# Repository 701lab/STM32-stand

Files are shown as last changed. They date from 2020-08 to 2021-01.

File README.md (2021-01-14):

# STM32 stand

В этом репозитории хранятся все исходные файлы печатных плат для лабораторного стенда по программированию STM32, разработанного в БГУИР.

Печатные платы разрабатывались с использованием Autodesk Eagle 9.6.1.

Кроме исходных файлов в данном репозитории можно также найти:
* файлы для заказа печатных плат;
* файлы для сборки печатных плат;
* документацию на платы оформленную почти под ЕСКД.

Данные файлы распространяются свободно и могут быть свободно использованы.

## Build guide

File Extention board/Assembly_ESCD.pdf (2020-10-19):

Формат А4

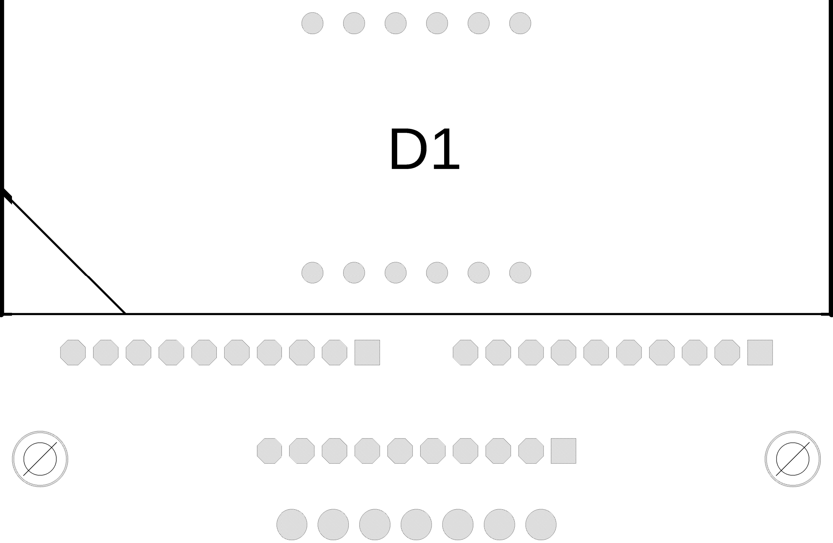
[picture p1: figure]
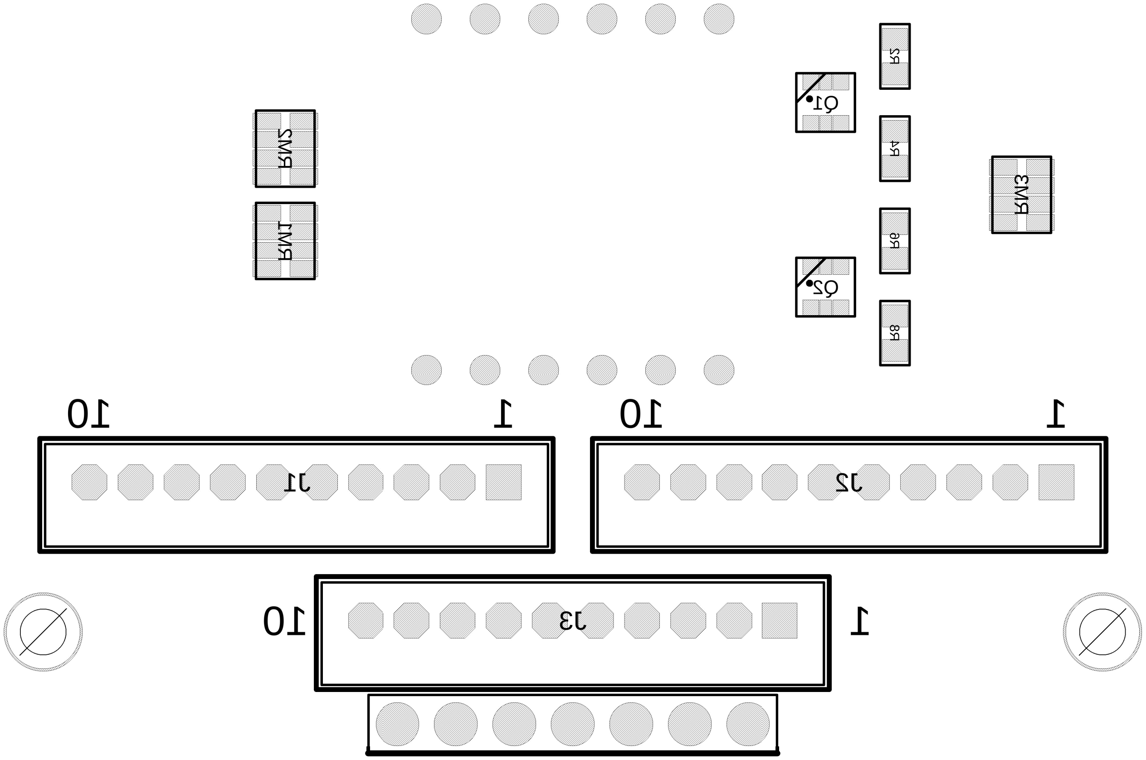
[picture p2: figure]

Изм. | Лист | № докум. | Подп. | Дата
Разраб.
Пров.
Лит | Лист | Листов

# ГУИР.411711.001 ПЭ3

Плата модуля расширения

Схема расположения

## БГУИР, каф. СУ

1 | 1

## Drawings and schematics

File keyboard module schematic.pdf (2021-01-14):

Цифровые входы-выходы | 7-мисегментный индикатор | Подключение клавиатуры

# 10 J1

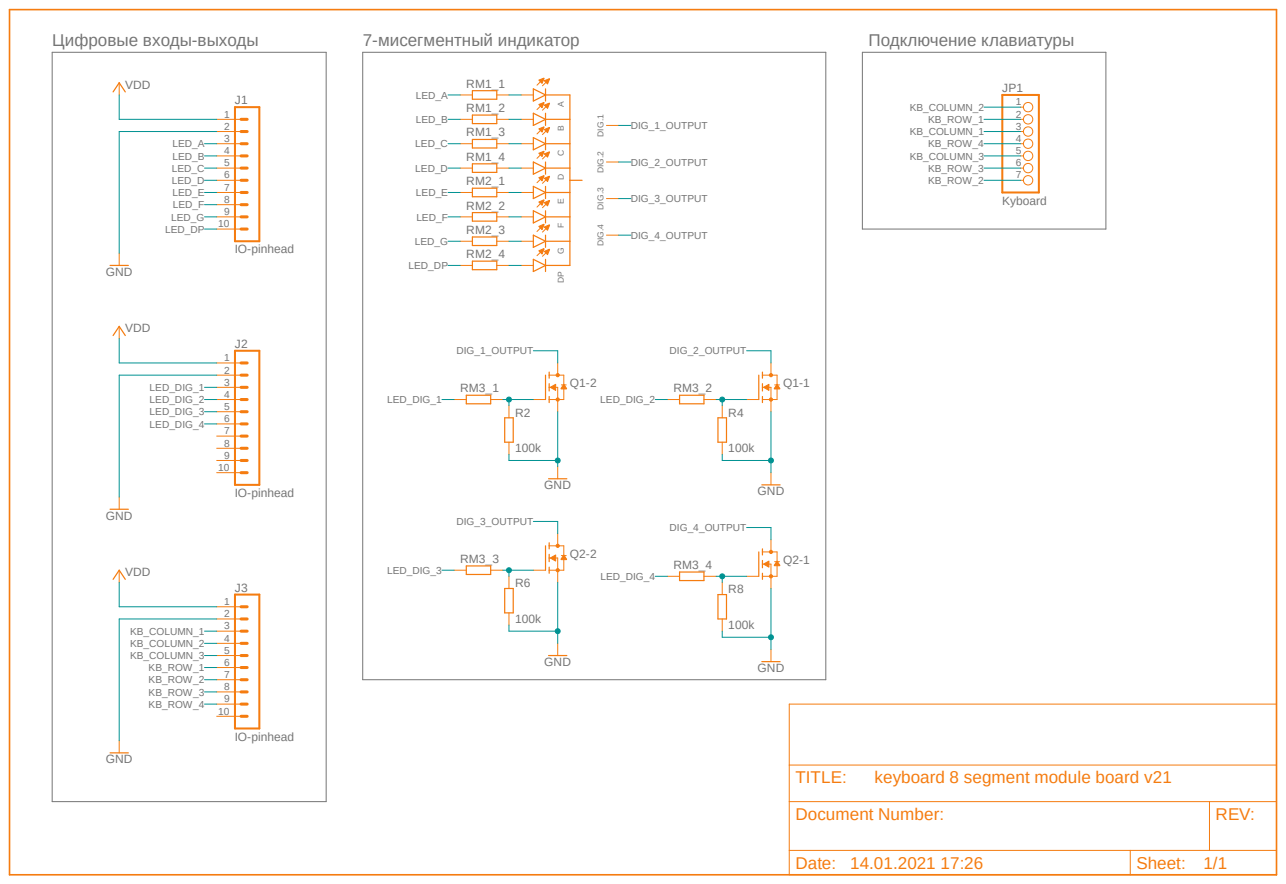
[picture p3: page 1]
VDD; GND; Kyboard; IO-pinhead; LED_A; LED_B; LED_C; LED_D; LED_E; LED_F; LED_G; LED_DIG_1; LED_DIG_2; LED_DIG_2 LED_DIG_1; LED_DIG_3; LED_DIG_4; KB_ROW_1; KB_COLUMN_1; KB_ROW_4; KB_COLUMN_3; KB_ROW_3; KB_ROW_2; KB_COLUMN_2; LED_DP; DIG_1_OUTPUT; DIG_2_OUTPUT; DIG_3_OUTPUT; DIG_4_OUTPUT; TITLE:

A B C D E F G DP DIG.1 DIG.2 DIG.3 DIG.4

keyboard 8 segment module board v21

Document Number: | REV:

Date: 14.01.2021 17:26 | Sheet: 1/1

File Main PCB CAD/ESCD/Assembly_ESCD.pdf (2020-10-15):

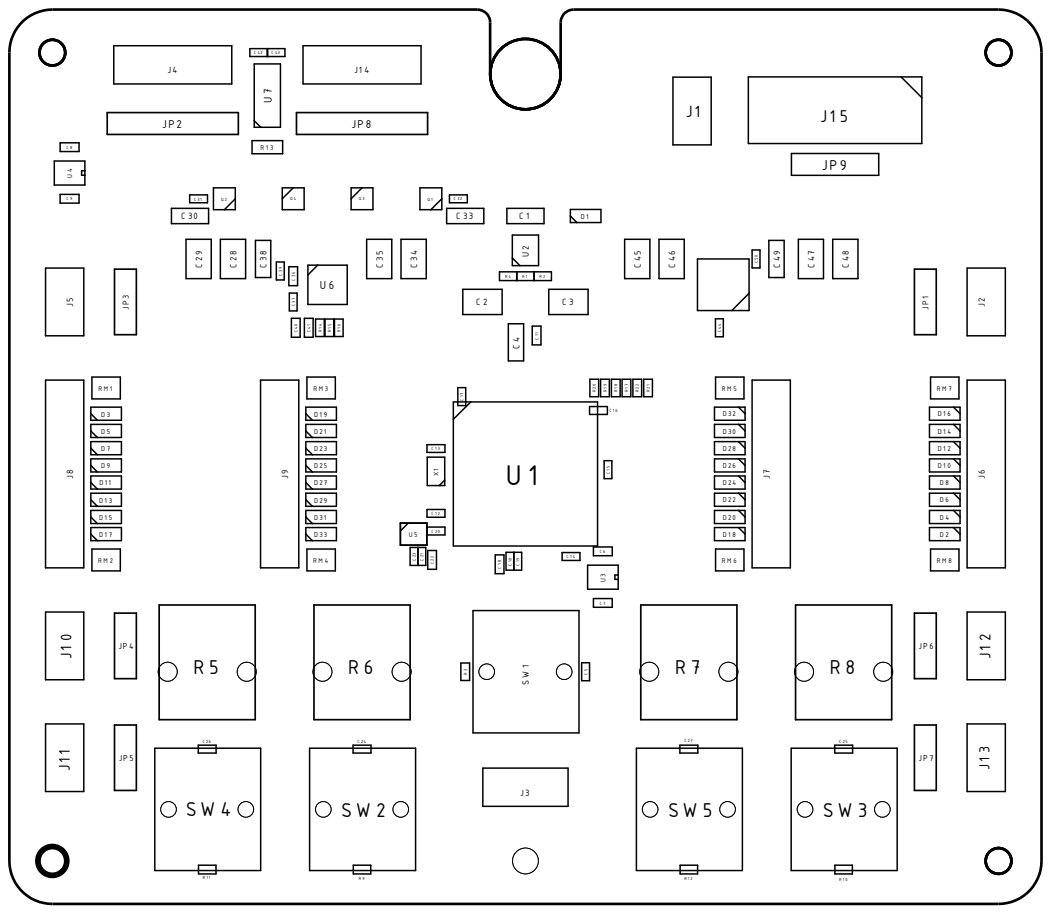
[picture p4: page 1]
Формат А4; Изм.; Лист; № докум.; Подп.; Дата; Разраб. Пров.; Лит; Листов; ГУИР.411711.001 ПЭ3; Плата управления стендом STM32; Схема расположения

БГУИР, каф. СУ

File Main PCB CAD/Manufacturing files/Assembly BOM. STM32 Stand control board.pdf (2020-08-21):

BOM. STM32 Stand control board | Electrical

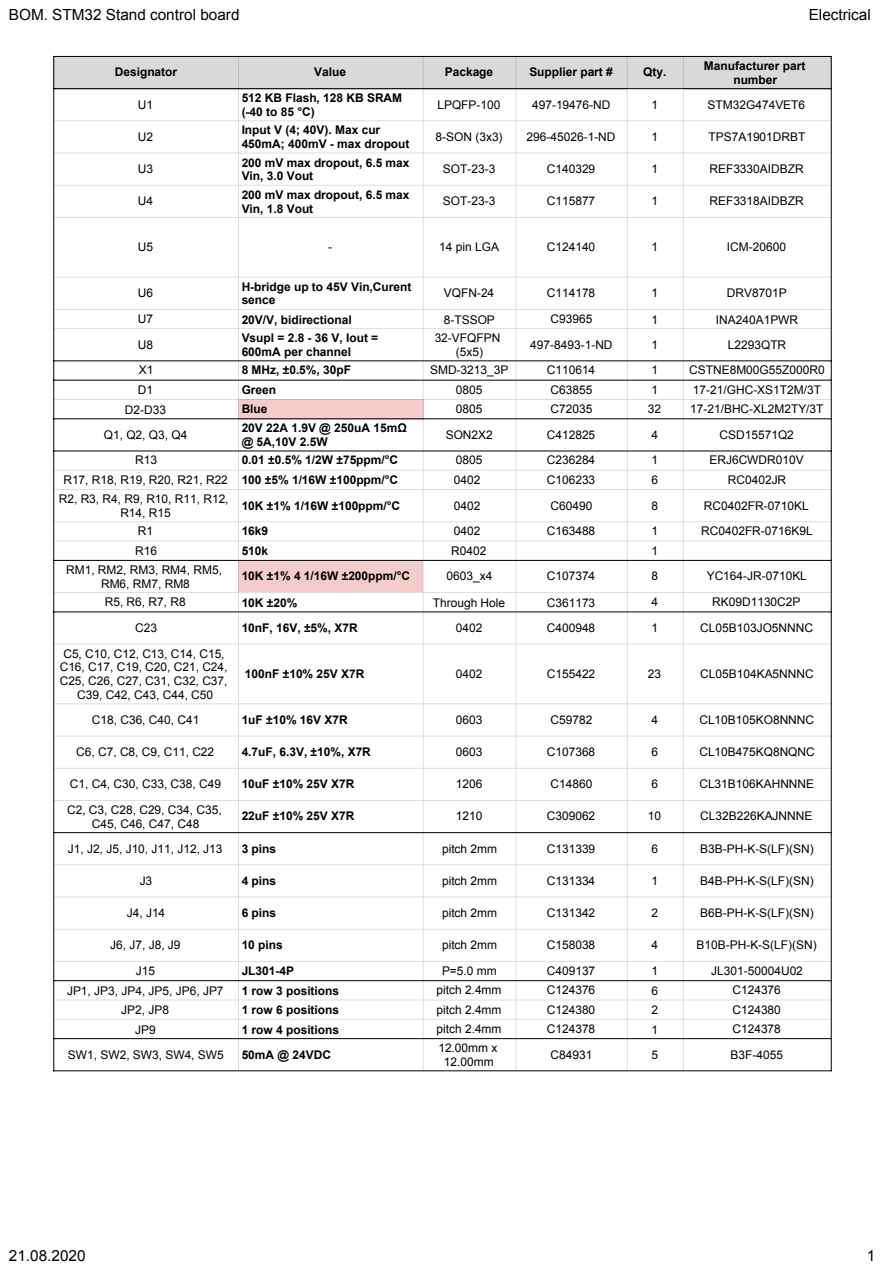
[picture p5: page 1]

U1 512 KB Flash, 128 KB SRAM (-40 to 85 °C) LPQFP-100 497-19476-ND U2 Input V (4; 40V). Max cur 450mA; 400mV - max dropout 8-SON (3x3) 296-45026-1-ND | 1 1 | STM32G474VET6 TPS7A1901DRBT

U5 U8 | Vin, 3.0 Vout SOT-23-3 Vin, 1.8 Vout SOT-23-3 | C140329 C115877 | 1 REF3330AIDBZR 1 REF3318AIDBZR

-14 pin LGA C124140 | 1 | ICM-20600

Vsupl = 2.8 - 36 V, Iout = 32-VFQFPN (5x5) 497-8493-1-ND 600mA per channel | 1 | L2293QTR

X1 | 8 MHz, ±0.5%, 30pF SMD-3213_3P C110614 1 CSTNE8M00G55Z000R0
D1 | Green 0805 C63855 | 1 | 17-21/GHC-XS1T2M/3T

Q1, Q2, Q3, Q4 | 20V 22A 1.9V @ 250uA 15mΩ @ 5A,10V 2.5W SON2X2 C412825 | 4 | CSD15571Q2

R13 R17, R18, R19, R20, R21, R22 R2, R3, R4, R9, R10, R11, R12, R14, R15 R1 R16 | 0.01 ±0.5% 1/2W ±75ppm/°C 0805 C236284 100 ±5% 1/16W ±100ppm/°C 0402 C106233 10K ±1% 1/16W ±100ppm/°C 0402 C60490 16k9 0402 C163488 510k R0402 | 1 6 8 1 1 | ERJ6CWDR010V RC0402JR RC0402FR-0710KL RC0402FR-0716K9L

J1, J2, J5, J10, J11, J12, J13 J3 J4, J14 J6, J7, J8, J9 J15 | 3 pins pitch 2mm C131339 4 pins pitch 2mm C131334 6 pins pitch 2mm C131342 10 pins pitch 2mm C158038 JL301-4P P=5.0 mm C409137 | 6 1 2 4 1 | B3B-PH-K-S(LF)(SN) B4B-PH-K-S(LF)(SN) B6B-PH-K-S(LF)(SN) B10B-PH-K-S(LF)(SN) JL301-50004U02

JP1, JP3, JP4, JP5, JP6, JP7 JP2, JP8 JP9 | 1 row 3 positions pitch 2.4mm C124376 1 row 6 positions pitch 2.4mm C124380 1 row 4 positions pitch 2.4mm C124378 | 6 C124376 2 C124380 1 C124378

SW1, SW2, SW3, SW4, SW5 | 50mA @ 24VDC 12.00mm x 12.00mm C84931 | 5 | B3F-4055

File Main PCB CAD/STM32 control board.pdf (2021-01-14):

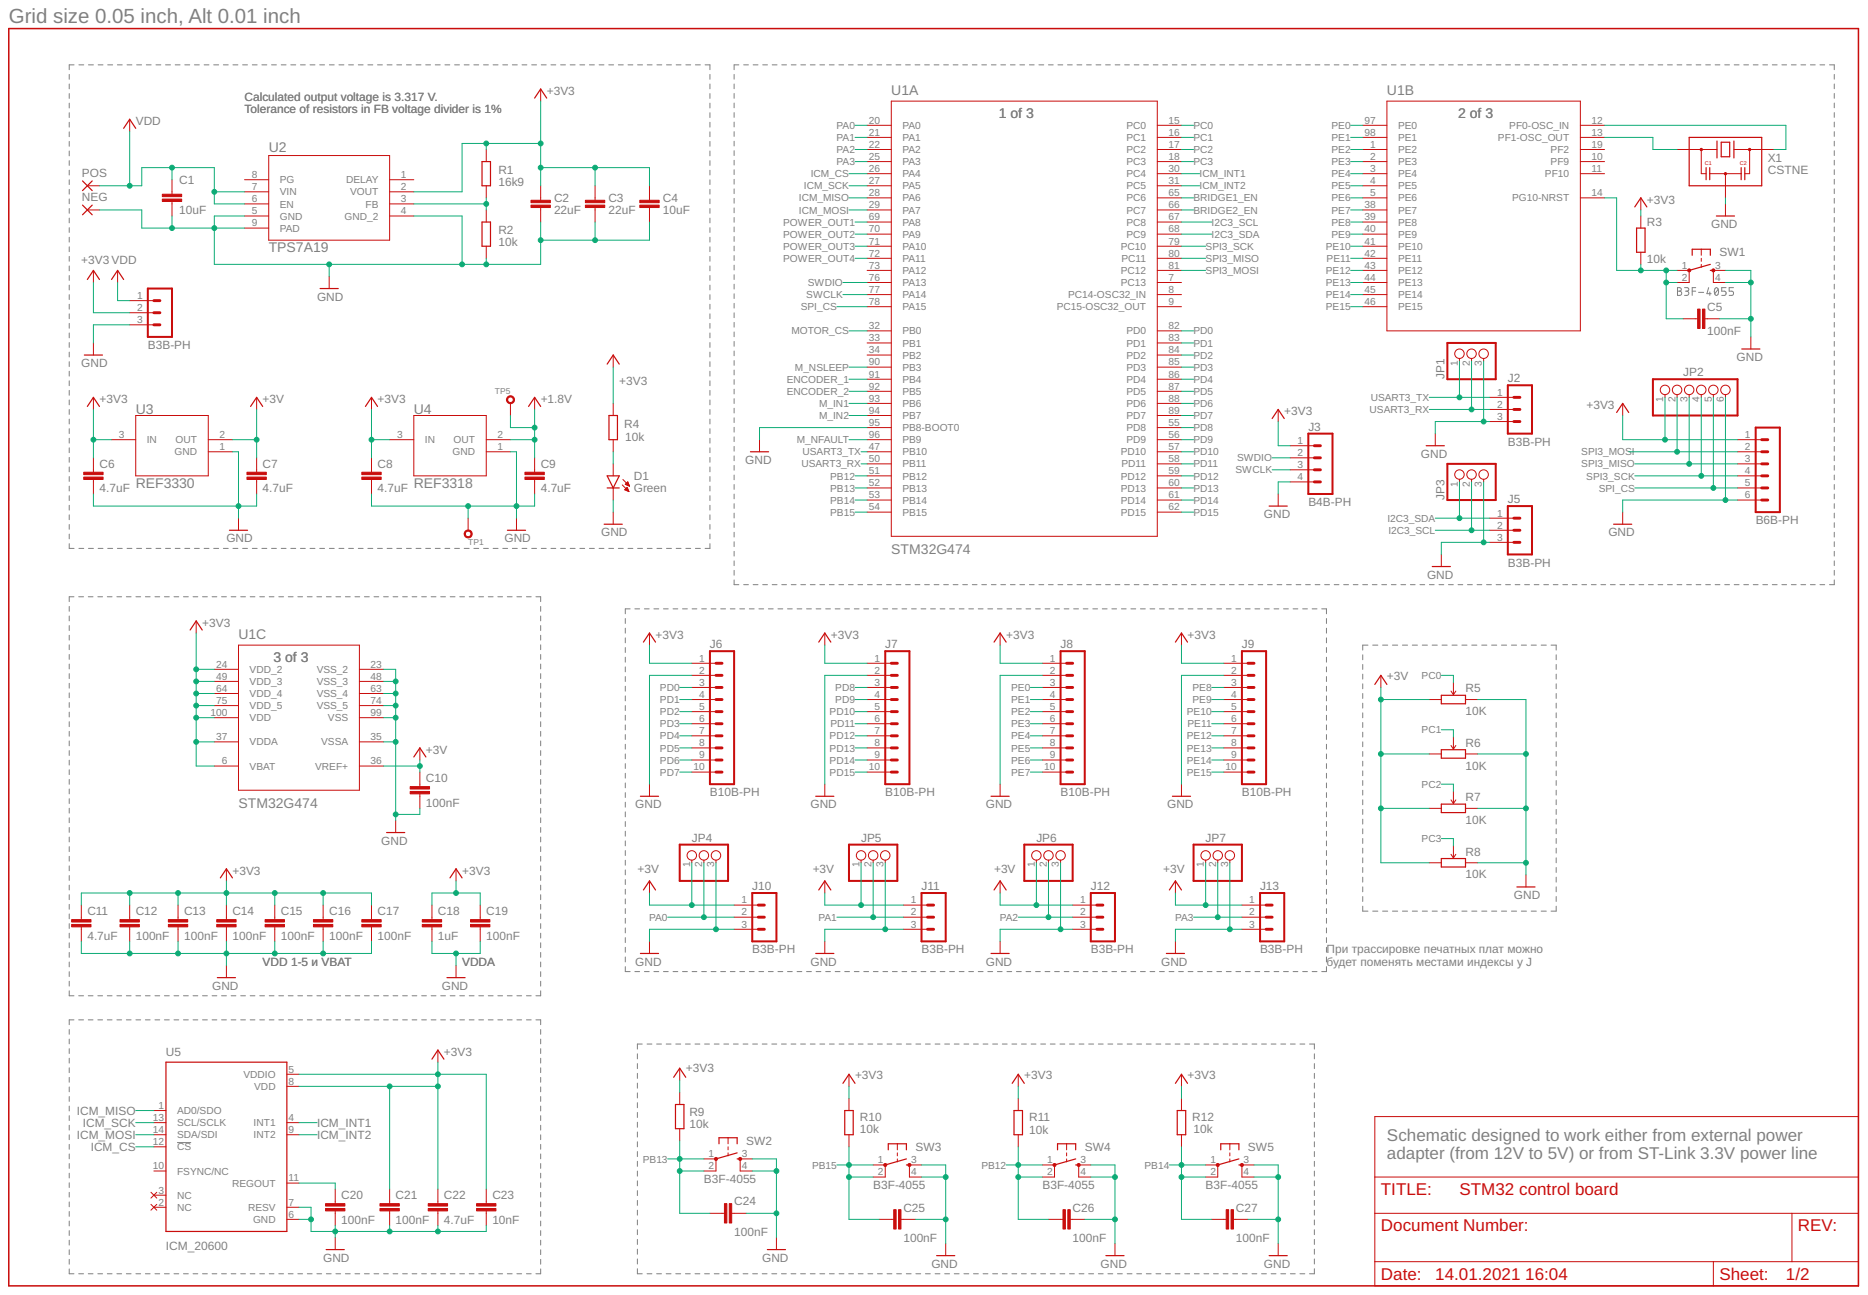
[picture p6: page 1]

Grid size 0.05 inch, Alt 0.01 inch

Calculated output voltage is 3.317 V. Tolerance of resistors in FB voltage divider is 1%

Schematic designed to work either from external power
adapter (from 12V to 5V) or from ST-Link 3.3V power line

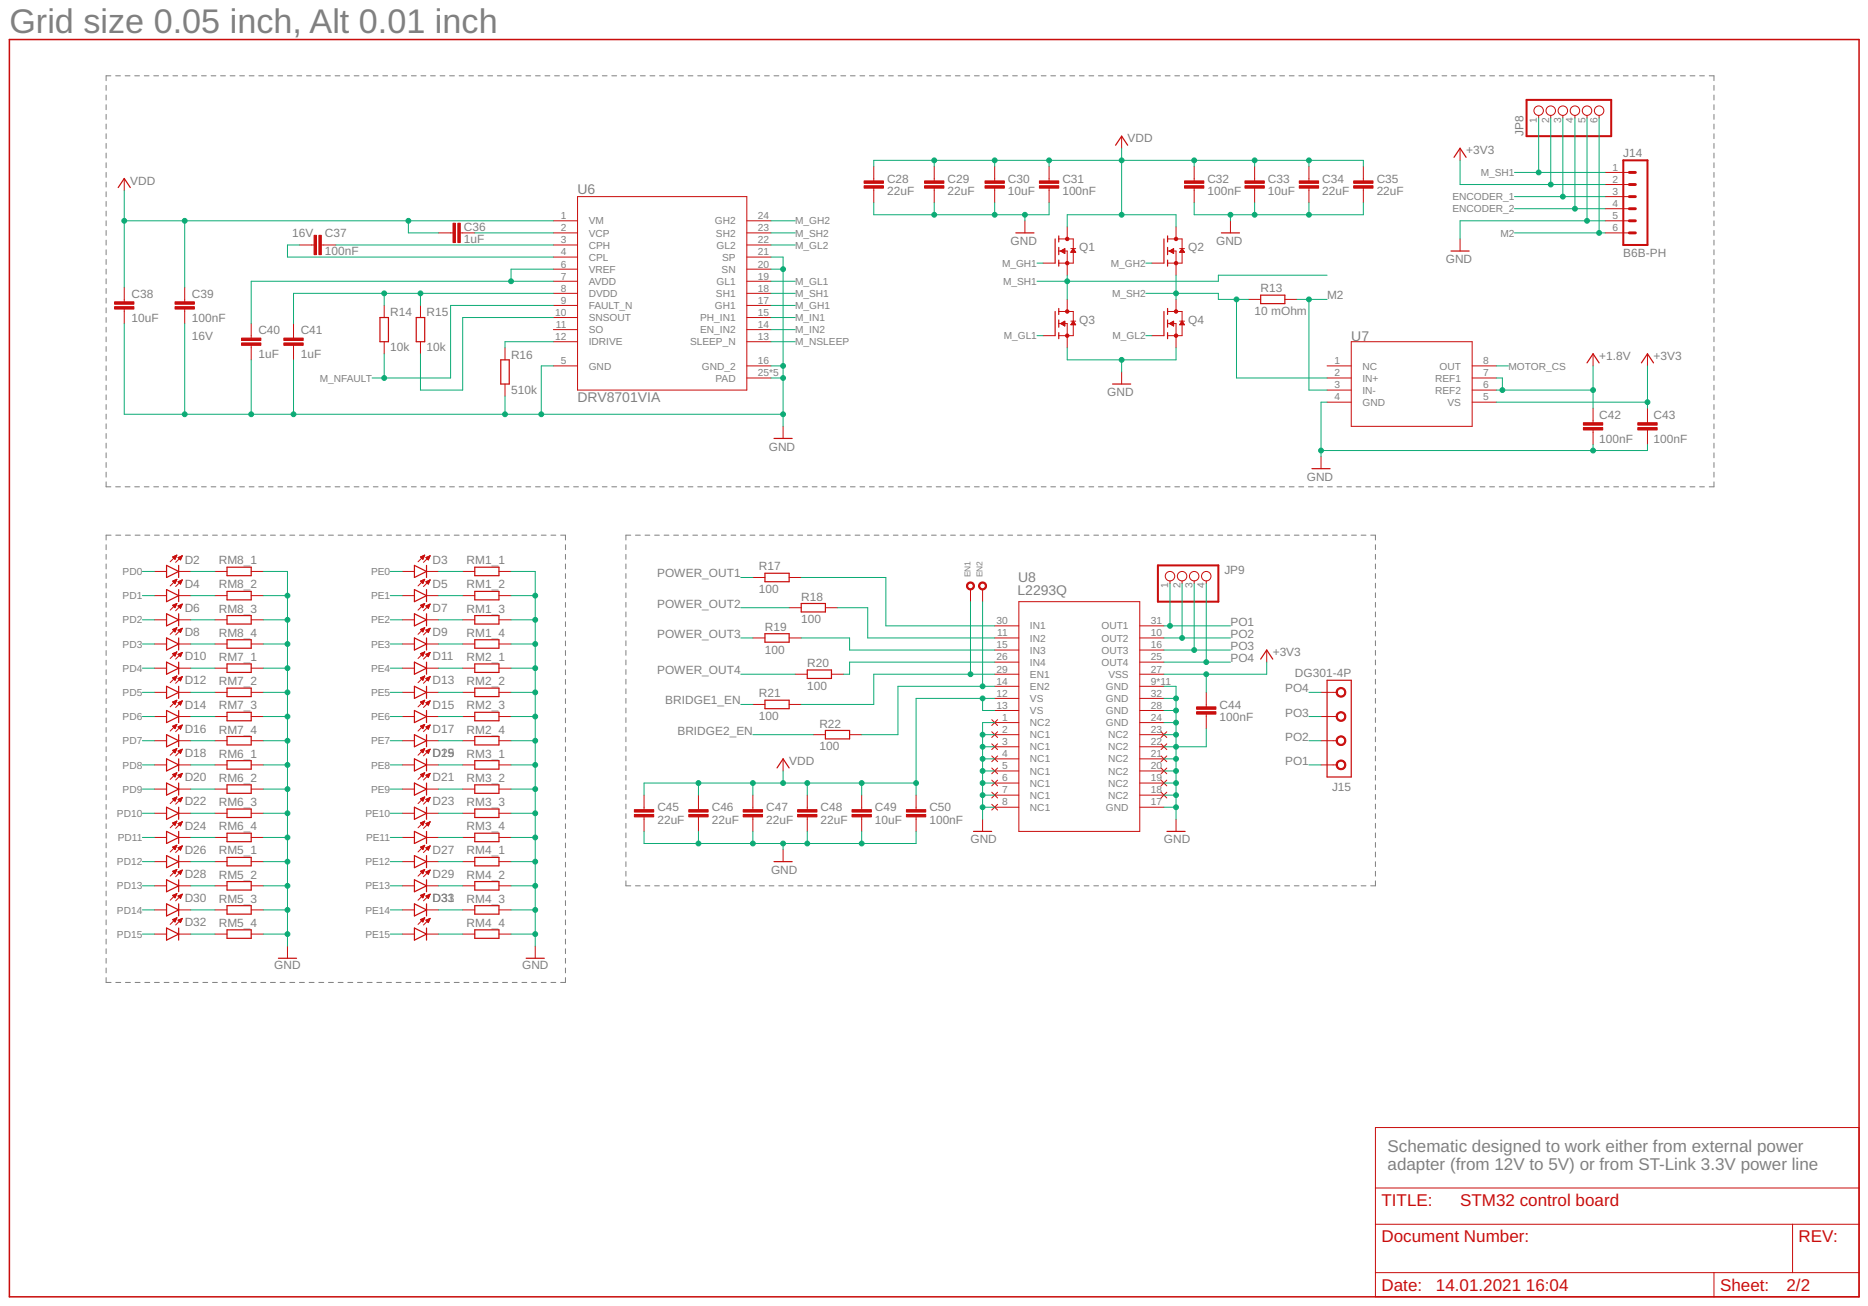
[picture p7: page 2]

Grid size 0.05 inch, Alt 0.01 inch

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

Document Number: | REV:

Date: 14.01.2021 16:04 | Sheet: 2/2

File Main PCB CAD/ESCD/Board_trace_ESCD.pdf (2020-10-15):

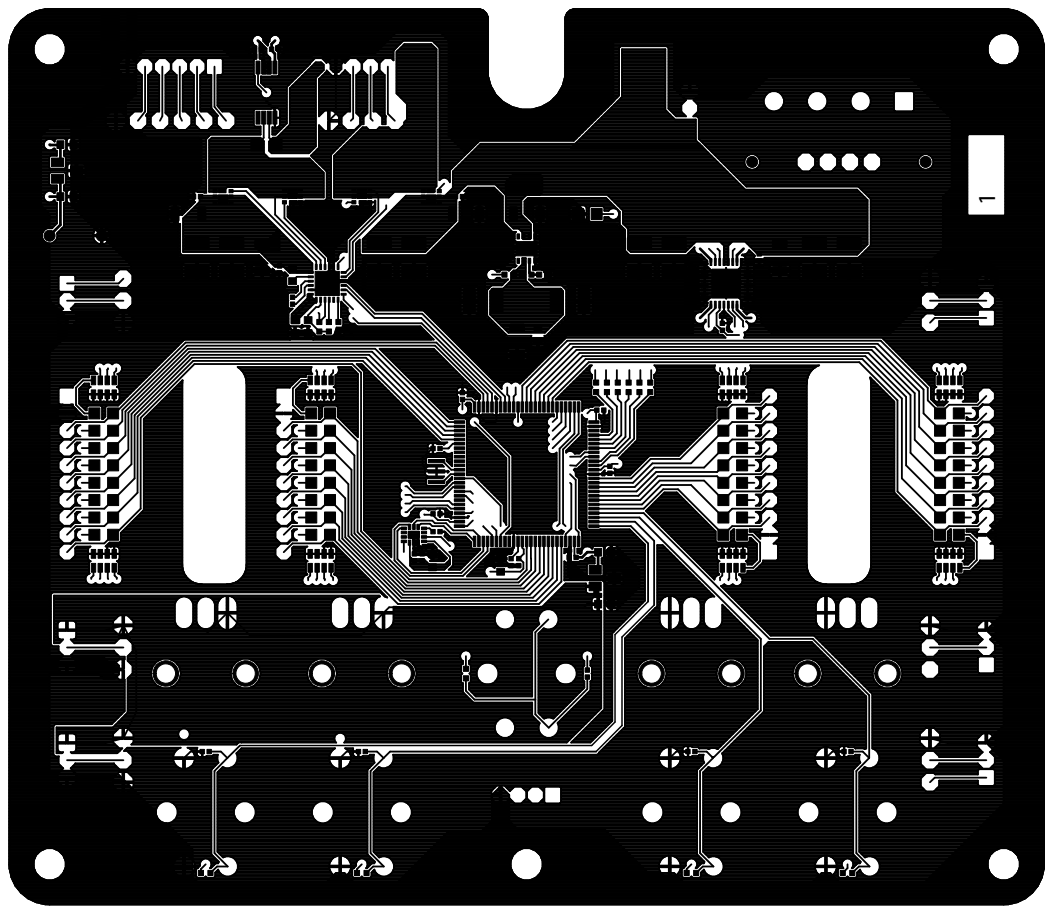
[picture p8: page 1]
Формат А4; Изм.; Лист; № докум.; Подп.; Дата; Разраб. Пров.; Лит; Листов; ГУИР.411711.001 ПЭ3; Плата управления стендом STM32

БГУИР, каф. СУ

Чертёж печатной платы: слой 1

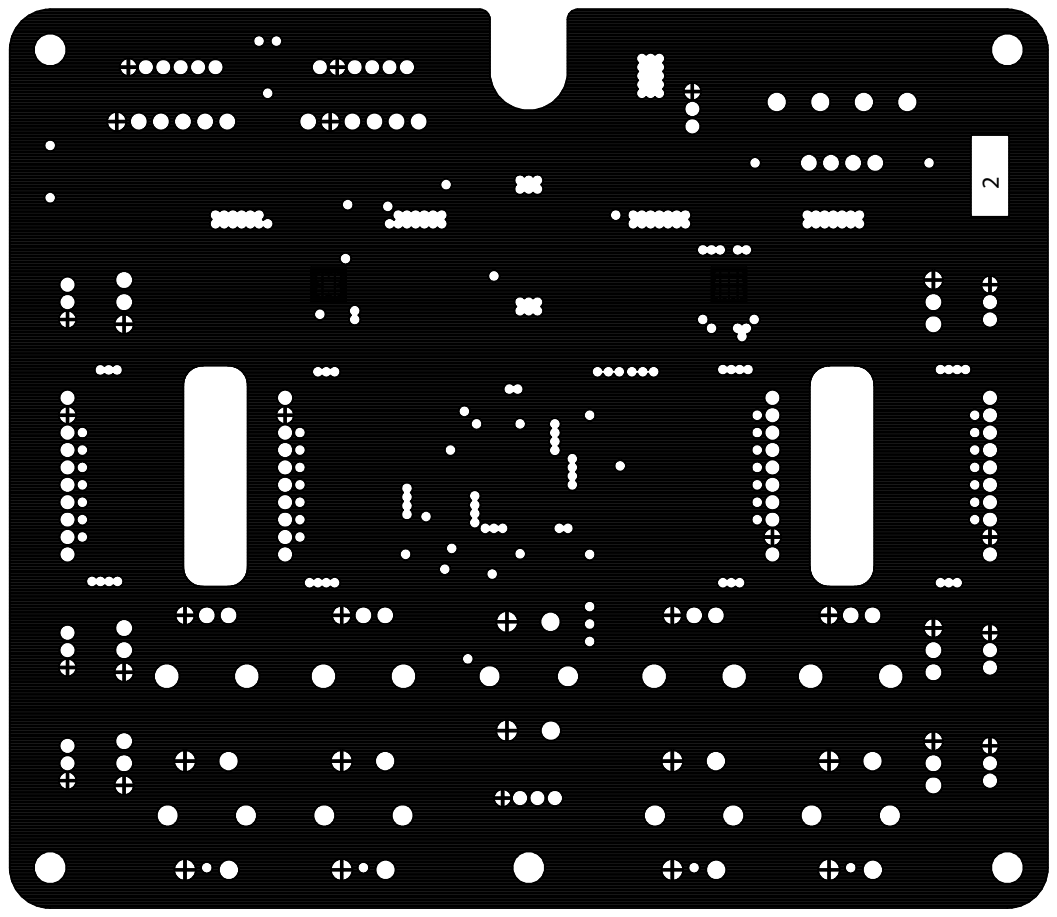
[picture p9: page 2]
Лит; Лист; Листов; ГУИР.411711.001 ПЭ3

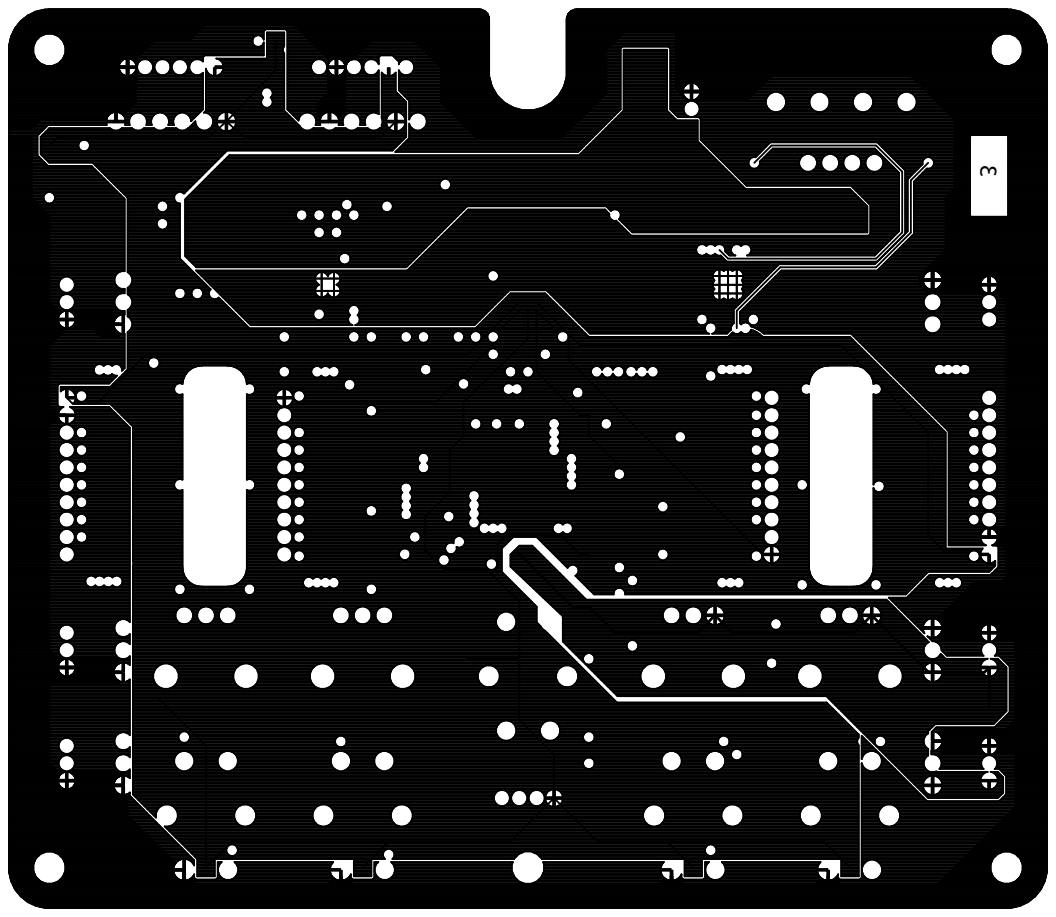
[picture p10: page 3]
Лит; Лист; Листов; ГУИР.411711.001 ПЭ3

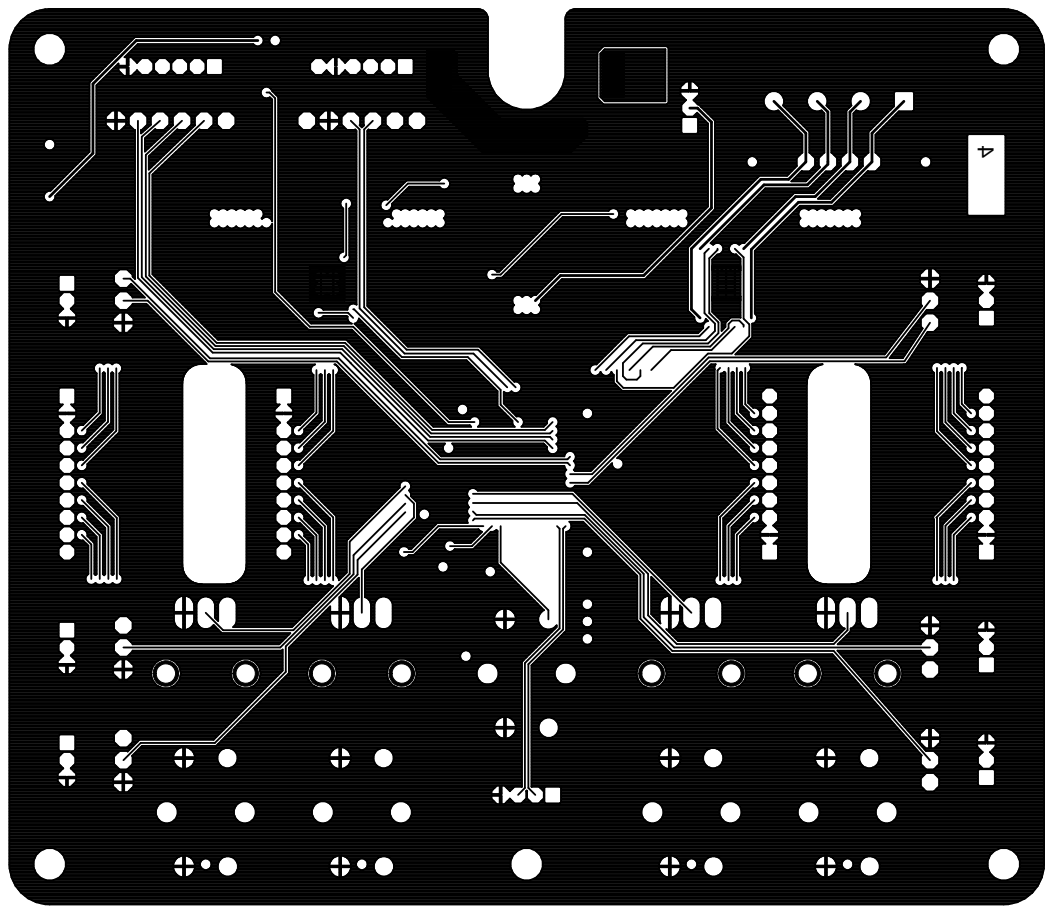
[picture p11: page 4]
Лит; Лист; Листов; ГУИР.411711.001 ПЭ3

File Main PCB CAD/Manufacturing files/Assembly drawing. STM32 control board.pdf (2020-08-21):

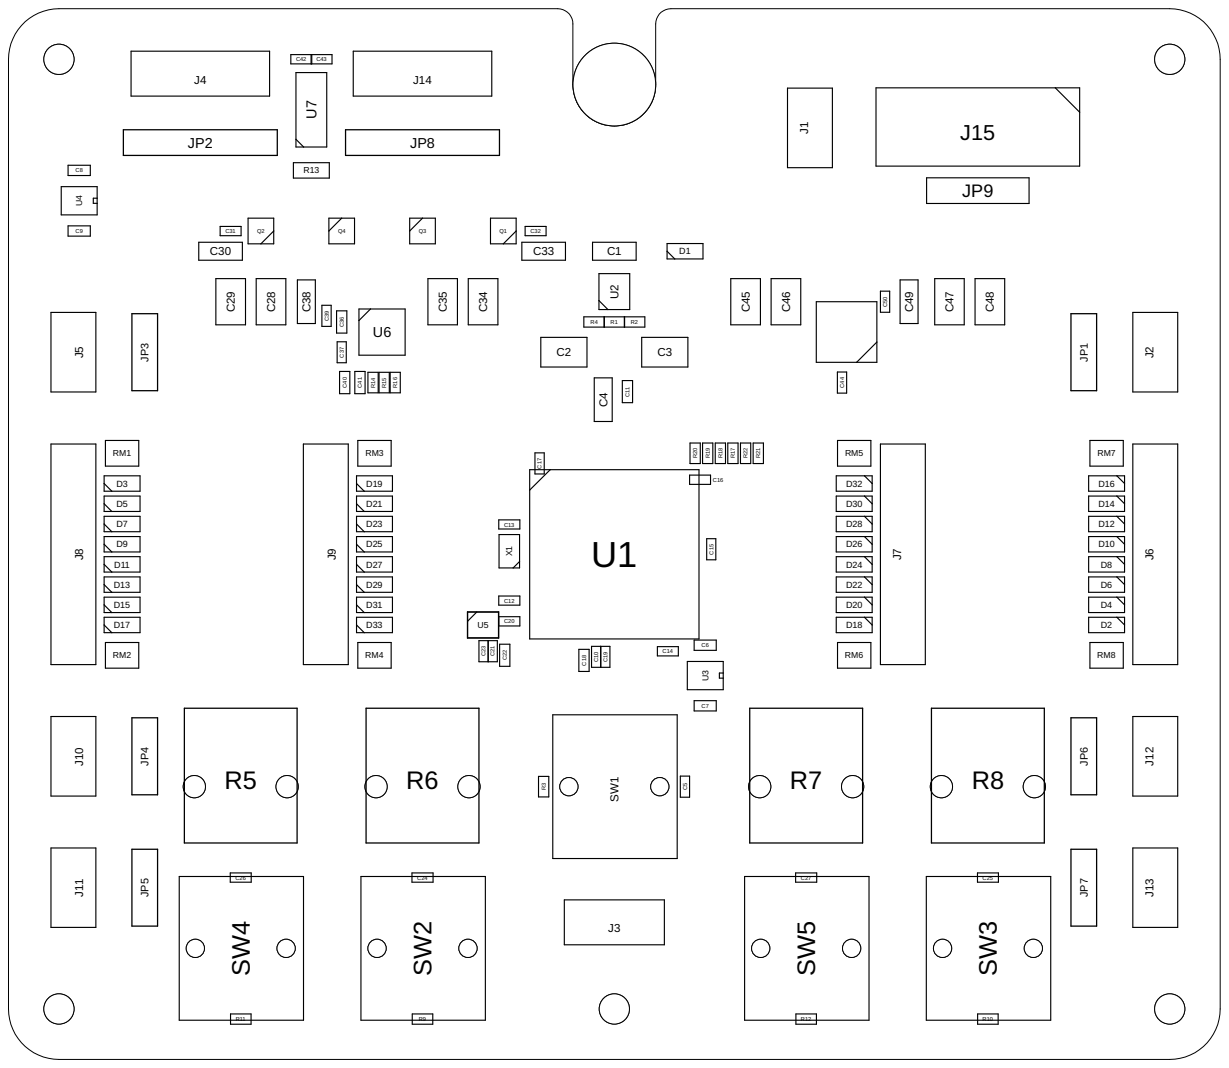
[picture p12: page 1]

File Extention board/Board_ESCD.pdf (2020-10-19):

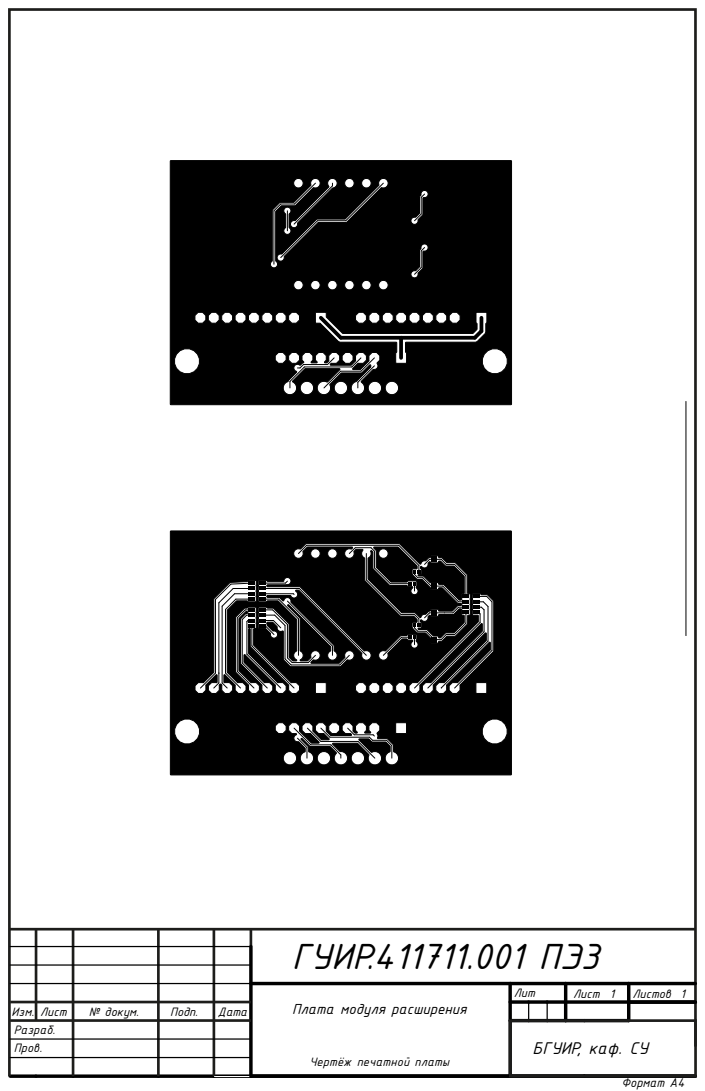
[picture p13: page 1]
Формат А4; Изм.; Лист; № докум.; Подп.; Дата; Разраб. Пров.; Лит; Листов; ГУИР.411711.001 ПЭ3

Плата модуля расширения

БГУИР, каф. СУ

Чертёж печатной платы

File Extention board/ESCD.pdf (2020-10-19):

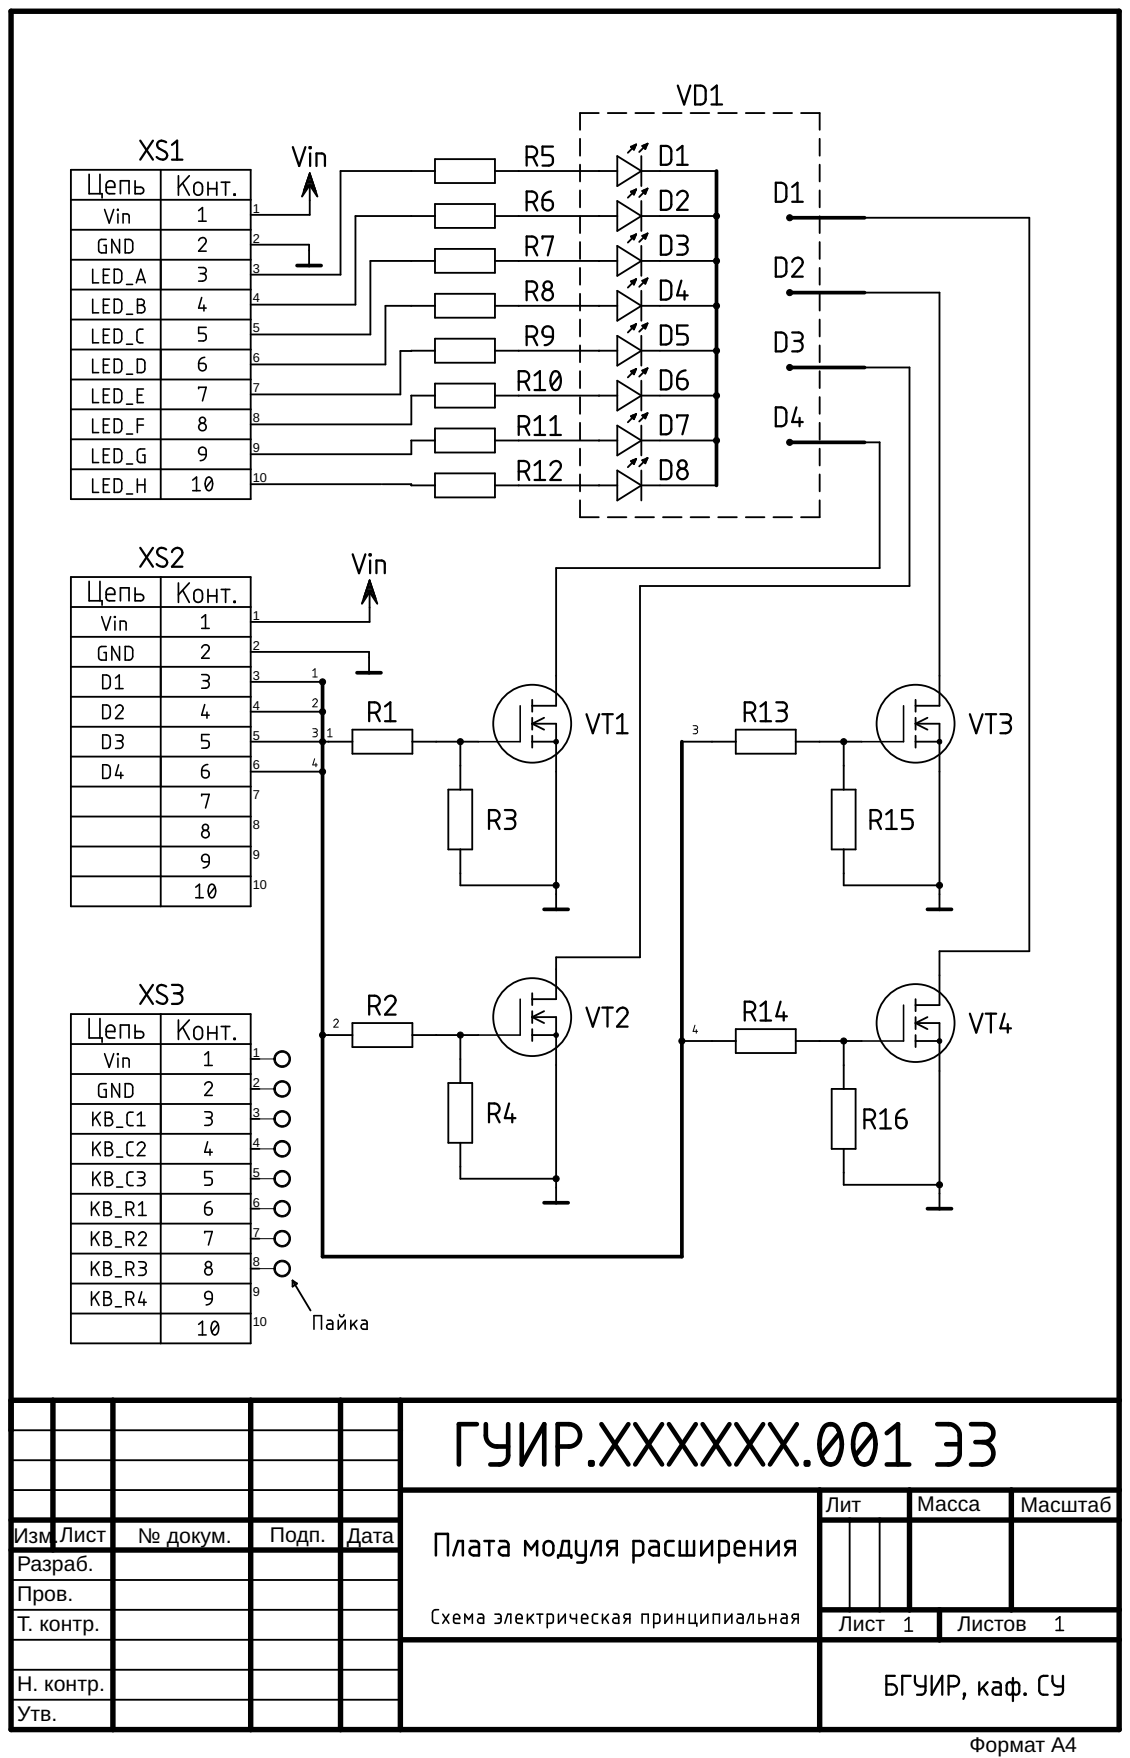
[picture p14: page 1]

Лит | Масса | Масштаб

Изм.Лист | № докум. | Подп. | Дата

Разраб. Пров. Т. контр. Н. контр. Утв.



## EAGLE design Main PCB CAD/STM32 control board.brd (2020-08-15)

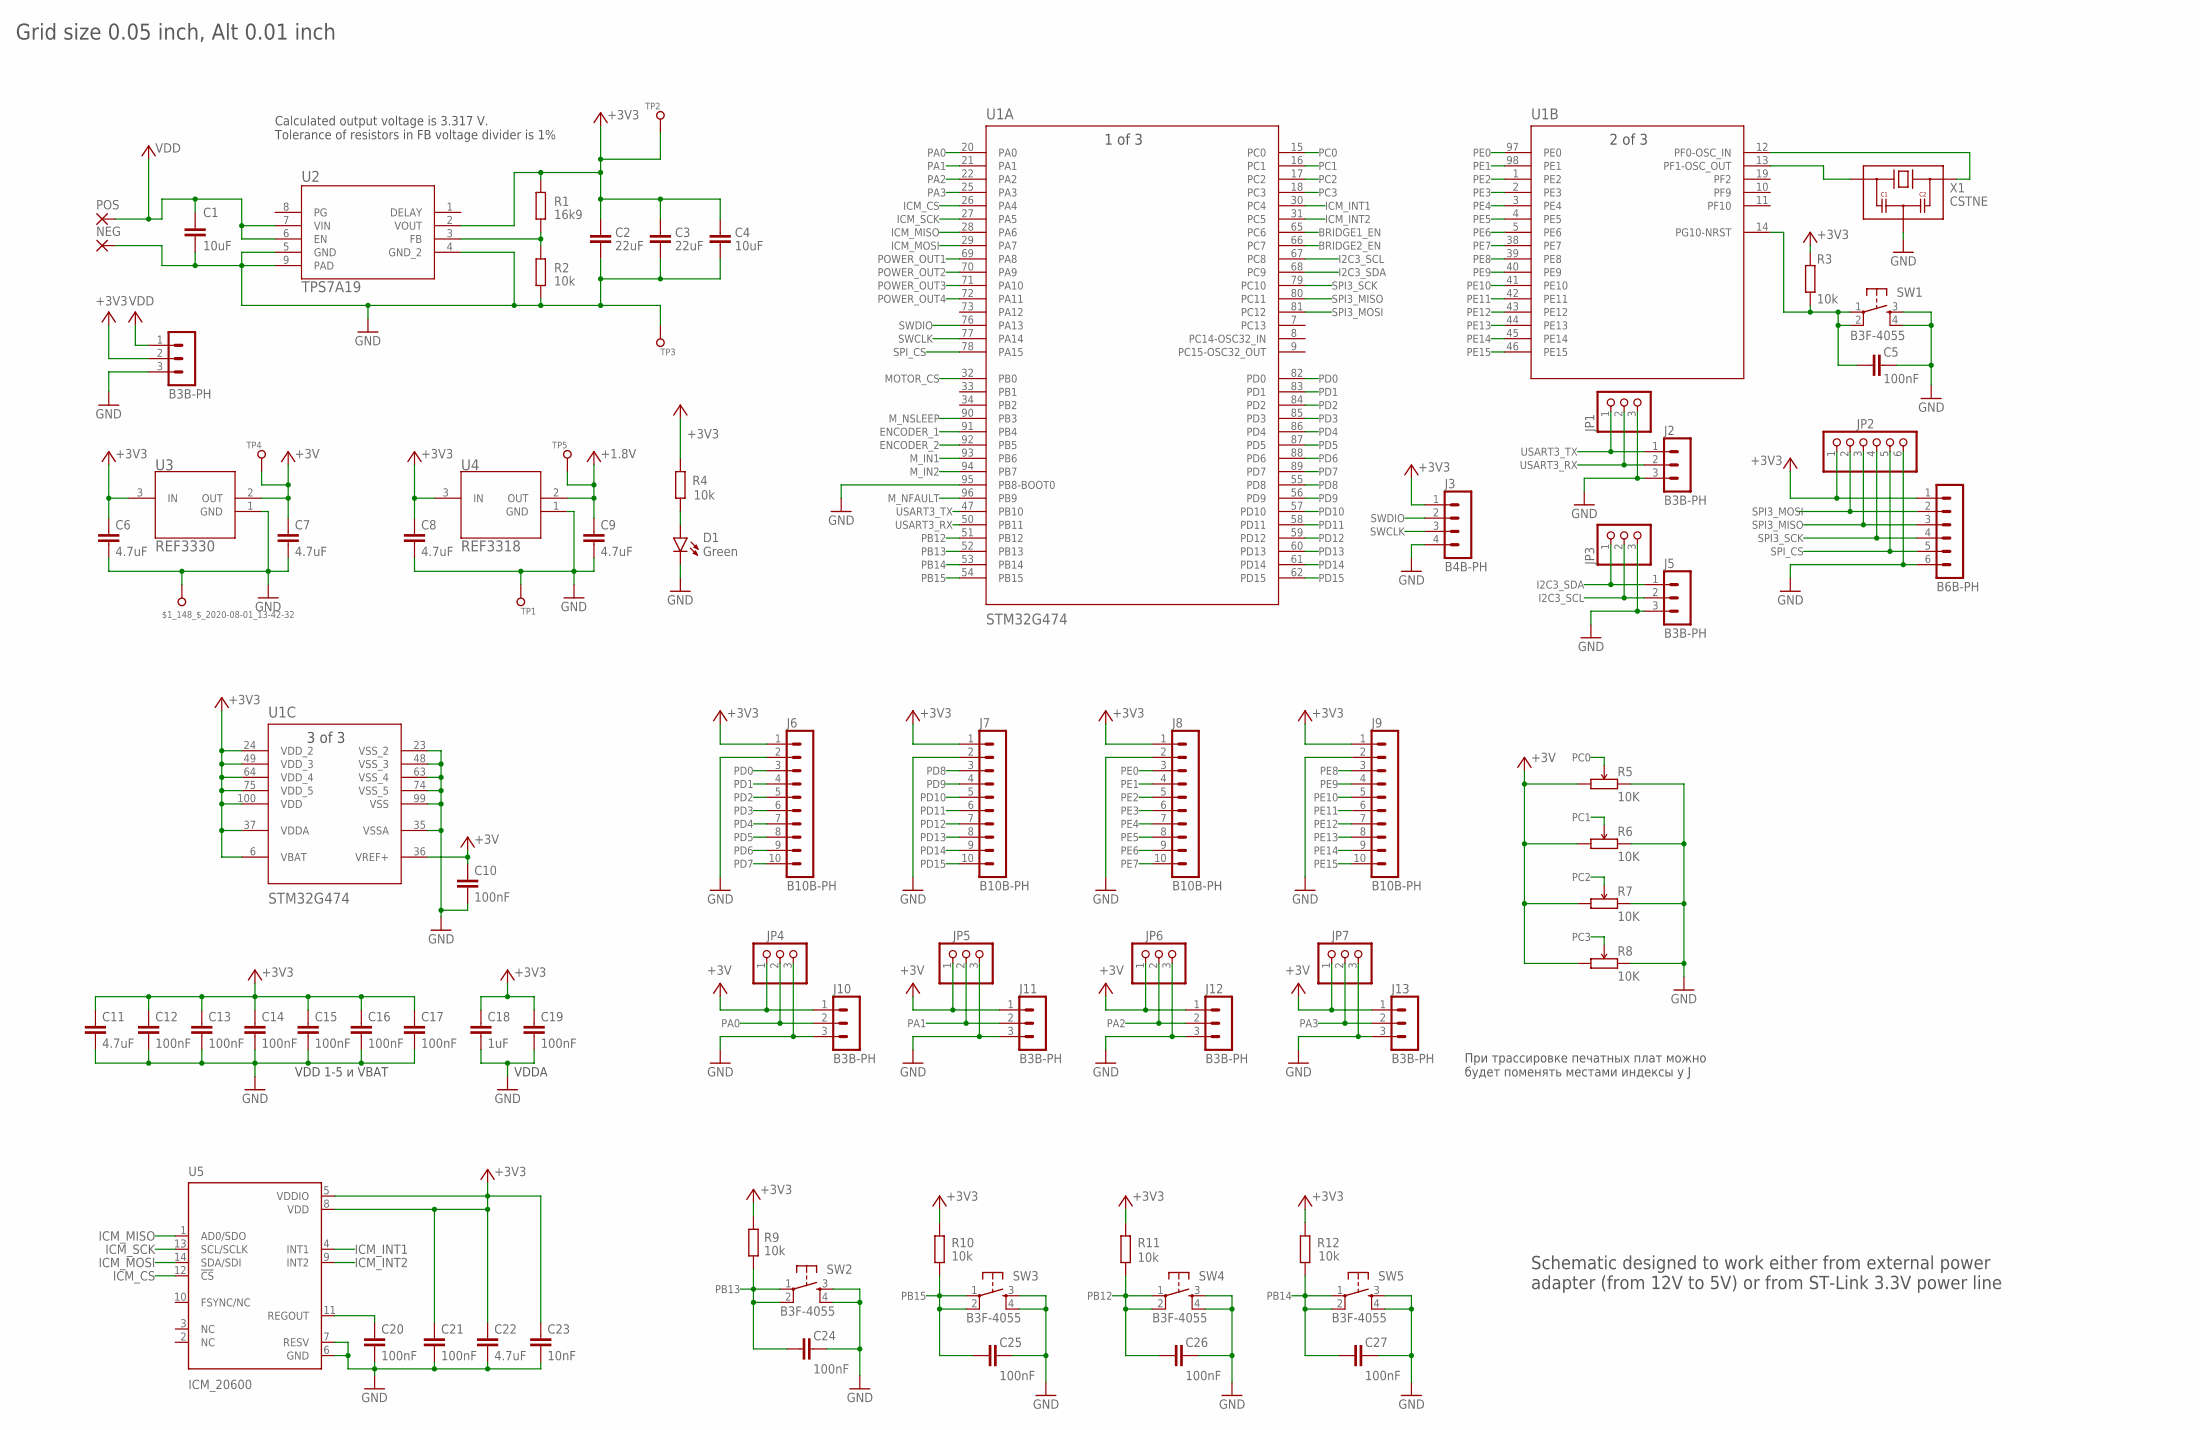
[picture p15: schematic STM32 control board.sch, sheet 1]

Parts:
$1_148_$_2020-08-01_13-42-32: TEST_PAD-[1.27MM_SK]; TP1.27MM_MASK_SILKSCREEN
C1, C4: 10uF; C1206; MANUFACTURER_PART_NUMBER CL31B106KAHNNNE
C2, C3: 22uF; C1210; MANUFACTURER_PART_NUMBER GRM32ER61C476ME15L
C5, C10, C12, C13, C14, C15, C16, C17, C19, C20, C21, C24, C25, C26, C27: 100nF; C0402
C6, C7, C8, C9, C11, C22: 4.7uF; C0603
C18: 1uF; C0603
C23: 10nF; C0402
D1: Green; LED-0805
J1, J2, J5, J10, J11, J12, J13: B3B-PH; B3B-PH-K
J3: B4B-PH; B4B-PH-K
J4: B6B-PH; B6B-PH-K
J6, J7, J8, J9: B10B-PH; B10B-PH-K
JP1, JP3, JP4, JP5, JP6, JP7: PINHD-1X3; 1X03
JP2: PINHD-1X6-OCT; 1X06
NEG: SMD_PAD
POS: SMD_PAD
R1: 16k9; R0402
R2, R3, R4, R9, R10, R11, R12: 10k; R0402
R5, R6, R7, R8: 10K; ALPS_PTM_LONG
SW1, SW2, SW3, SW4, SW5: B3F-4055; SWITCH_B3F-4055
TP1, TP2, TP3, TP5: 1.8; TP1.27MM_MASK_SILKSCREEN
TP4: 3.0; TP1.27MM_MASK_SILKSCREEN
U1: STM32G474; LPQFP-100
U2: TPS7A19; DRB0008B
U3: REF3330; SOT-23-3
U4: REF3318; SOT-23-3
U5: ICM_20600; 14_PIN_LGA
X1: CSTNE; MURATA_SMD_3P

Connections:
+1.8V: C9.1, TP5.1, U4.2 (OUT); also elsewhere on the board
+3V: C7.1, C10.1, J10.1, J11.1, J12.1, J13.1, JP4.1, JP5.1, JP6.1, JP7.1, R5.P$1 (1), R6.P$1 (1), R7.P$1 (1), R8.P$1 (1), TP4.1, U1.36 (VREF+), U3.2 (OUT)
+3V3: C2.1, C3.1, C4.1, C6.1, C8.1, C11.1, C12.1, C13.1, C14.1, C15.1, C16.1, C17.1, C18.1, C19.1, C21.1, C22.1, C23.1, J1.2, J3.1, J4.1, J6.1, J7.1, J8.1, J9.1, JP2.1, R1.2, R3.1, R4.2, R9.2, R10.2, R11.2, R12.2, TP2.1, U1.6 (VBAT), U1.24 (VDD_2), U1.37 (VDDA), U1.49 (VDD_3), U1.64 (VDD_4), U1.75 (VDD_5), U1.100 (VDD), U2.2 (VOUT), U3.3 (IN), U4.3 (IN), U5.5 (VDDIO), U5.8 (VDD); also elsewhere on the board
BRIDGE1_EN: U1.65 (PC6); also elsewhere on the board
BRIDGE2_EN: U1.66 (PC7); also elsewhere on the board
ENCODER_1: U1.91 (PB4); also elsewhere on the board
ENCODER_2: U1.92 (PB5); also elsewhere on the board
GND: $1_148_$_2020-08-01_13-42-32.1, C1.2, C2.2, C3.2, C4.2, C5.2, C6.2, C7.2, C8.2, C9.2, C10.2, C11.2, C12.2, C13.2, C14.2, C15.2, C16.2, C17.2, C18.2, C19.2, C20.2, C21.2, C22.2, C23.2, C24.2, C25.2, C26.2, C27.2, D1.- (C), J1.3, J2.3, J3.4, J4.6, J5.3, J6.2, J7.2, J8.2, J9.2, J10.3, J11.3, J12.3, J13.3, JP1.3, JP2.6, JP3.3, JP4.3, JP5.3, JP6.3, JP7.3, NEG.1, R2.1, R5.P$3 (3), R6.P$3 (3), R7.P$3 (3), R8.P$3 (3), SW1.3, SW1.4, SW2.3, SW2.4, SW3.3, SW3.4, SW4.3, SW4.4, SW5.3, SW5.4, TP1.1, TP3.1, U1.23 (VSS_2), U1.35 (VSSA), U1.48 (VSS_3), U1.63 (VSS_4), U1.74 (VSS_5), U1.95 (PB8-BOOT0), U1.99 (VSS), U2.4 (GND_2), U2.5 (GND), U2.9 (PAD), U3.1 (GND), U4.1 (GND), U5.6 (GND), U5.7 (RESV), X1.2 (GND); also elsewhere on the board
I2C3_SCL: J5.2, JP3.2, U1.67 (PC8)
I2C3_SDA: J5.1, JP3.1, U1.68 (PC9)
ICM_CS: U1.26 (PA4), U5.12 (!CS)
ICM_INT1: U1.30 (PC4), U5.4 (INT1)
ICM_INT2: U1.31 (PC5), U5.9 (INT2)
ICM_MISO: U1.28 (PA6), U5.1 (AD0/SDO)
ICM_MOSI: U1.29 (PA7), U5.14 (SDA/SDI)
ICM_SCK: U1.27 (PA5), U5.13 (SCL/SCLK)
MOTOR_CS: U1.32 (PB0); also elsewhere on the board
M_IN1: U1.93 (PB6); also elsewhere on the board
M_IN2: U1.94 (PB7); also elsewhere on the board
M_NFAULT: U1.96 (PB9); also elsewhere on the board
M_NSLEEP: U1.90 (PB3); also elsewhere on the board
unnamed: U1.12 (PF0-OSC_IN), X1.3 (OUT)
unnamed: U1.13 (PF1-OSC_OUT), X1.1 (IN)
unnamed: D1.+ (A), R4.1
unnamed: R1.1, R2.2, U2.3 (FB)
PA0: J10.2, JP4.2, U1.20 (PA0)
PA1: J11.2, JP5.2, U1.21 (PA1)
PA2: J12.2, JP6.2, U1.22 (PA2)
PA3: J13.2, JP7.2, U1.25 (PA3)
PB12: C26.1, R11.1, SW4.1, SW4.2, U1.51 (PB12)
PB13: C24.1, R9.1, SW2.1, SW2.2, U1.52 (PB13)
PB14: C27.1, R12.1, SW5.1, SW5.2, U1.53 (PB14)
PB15: C25.1, R10.1, SW3.1, SW3.2, U1.54 (PB15)
PC0: R5.P$2 (2), U1.15 (PC0)
PC1: R6.P$2 (2), U1.16 (PC1)
PC2: R7.P$2 (2), U1.17 (PC2)
PC3: R8.P$2 (2), U1.18 (PC3)
PD0: J6.3, U1.82 (PD0); also elsewhere on the board
PD1: J6.4, U1.83 (PD1); also elsewhere on the board
PD2: J6.5, U1.84 (PD2); also elsewhere on the board
PD3: J6.6, U1.85 (PD3); also elsewhere on the board
PD4: J6.7, U1.86 (PD4); also elsewhere on the board
PD5: J6.8, U1.87 (PD5); also elsewhere on the board
PD6: J6.9, U1.88 (PD6); also elsewhere on the board
PD7: J6.10, U1.89 (PD7); also elsewhere on the board
PD8: J7.3, U1.55 (PD8); also elsewhere on the board
PD9: J7.4, U1.56 (PD9); also elsewhere on the board
PD10: J7.5, U1.57 (PD10); also elsewhere on the board
PD11: J7.6, U1.58 (PD11); also elsewhere on the board
PD12: J7.7, U1.59 (PD12); also elsewhere on the board
PD13: J7.8, U1.60 (PD13); also elsewhere on the board
PD14: J7.9, U1.61 (PD14); also elsewhere on the board
PD15: J7.10, U1.62 (PD15); also elsewhere on the board
PE0: J8.3, U1.97 (PE0); also elsewhere on the board
PE1: J8.4, U1.98 (PE1); also elsewhere on the board
PE2: J8.5, U1.1 (PE2); also elsewhere on the board
PE3: J8.6, U1.2 (PE3); also elsewhere on the board
PE4: J8.7, U1.3 (PE4); also elsewhere on the board
PE5: J8.8, U1.4 (PE5); also elsewhere on the board
PE6: J8.9, U1.5 (PE6); also elsewhere on the board
PE7: J8.10, U1.38 (PE7); also elsewhere on the board
PE8: J9.3, U1.39 (PE8); also elsewhere on the board
PE9: J9.4, U1.40 (PE9); also elsewhere on the board
PE10: J9.5, U1.41 (PE10); also elsewhere on the board
PE11: J9.6, U1.42 (PE11); also elsewhere on the board
PE12: J9.7, U1.43 (PE12); also elsewhere on the board
PE13: J9.8, U1.44 (PE13); also elsewhere on the board
PE14: J9.9, U1.45 (PE14); also elsewhere on the board
PE15: J9.10, U1.46 (PE15); also elsewhere on the board
POWER_OUT1: U1.69 (PA8); also elsewhere on the board
POWER_OUT2: U1.70 (PA9); also elsewhere on the board
POWER_OUT3: U1.71 (PA10); also elsewhere on the board
POWER_OUT4: U1.72 (PA11); also elsewhere on the board
REG: C20.1, U5.11 (REGOUT)
RST: C5.1, R3.2, SW1.1, SW1.2, U1.14 (PG10-NRST)
SPI3_MISO: J4.3, JP2.3, U1.80 (PC11)
SPI3_MOSI: J4.2, JP2.2, U1.81 (PC12)
SPI3_SCK: J4.4, JP2.4, U1.79 (PC10)
SPI_CS: J4.5, JP2.5, U1.78 (PA15)
SWCLK: J3.3, U1.77 (PA14)
SWDIO: J3.2, U1.76 (PA13)
USART3_RX: J2.2, JP1.2, U1.50 (PB11)
USART3_TX: J2.1, JP1.1, U1.47 (PB10)
VDD: C1.1, J1.1, POS.1, U2.6 (EN), U2.7 (VIN); also elsewhere on the board

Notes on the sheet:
Grid size 0.05 inch, Alt 0.01 inch
VDD 1-5 и VBAT
VDDA
Calculated output voltage is 3.317 V. Tolerance of resistors in FB voltage divider is 1%
Schematic designed to work either from external power adapter (from 12V to 5V) or from ST-Link 3.3V power line
При трассировке печатных плат можно будет поменять местами индексы у J

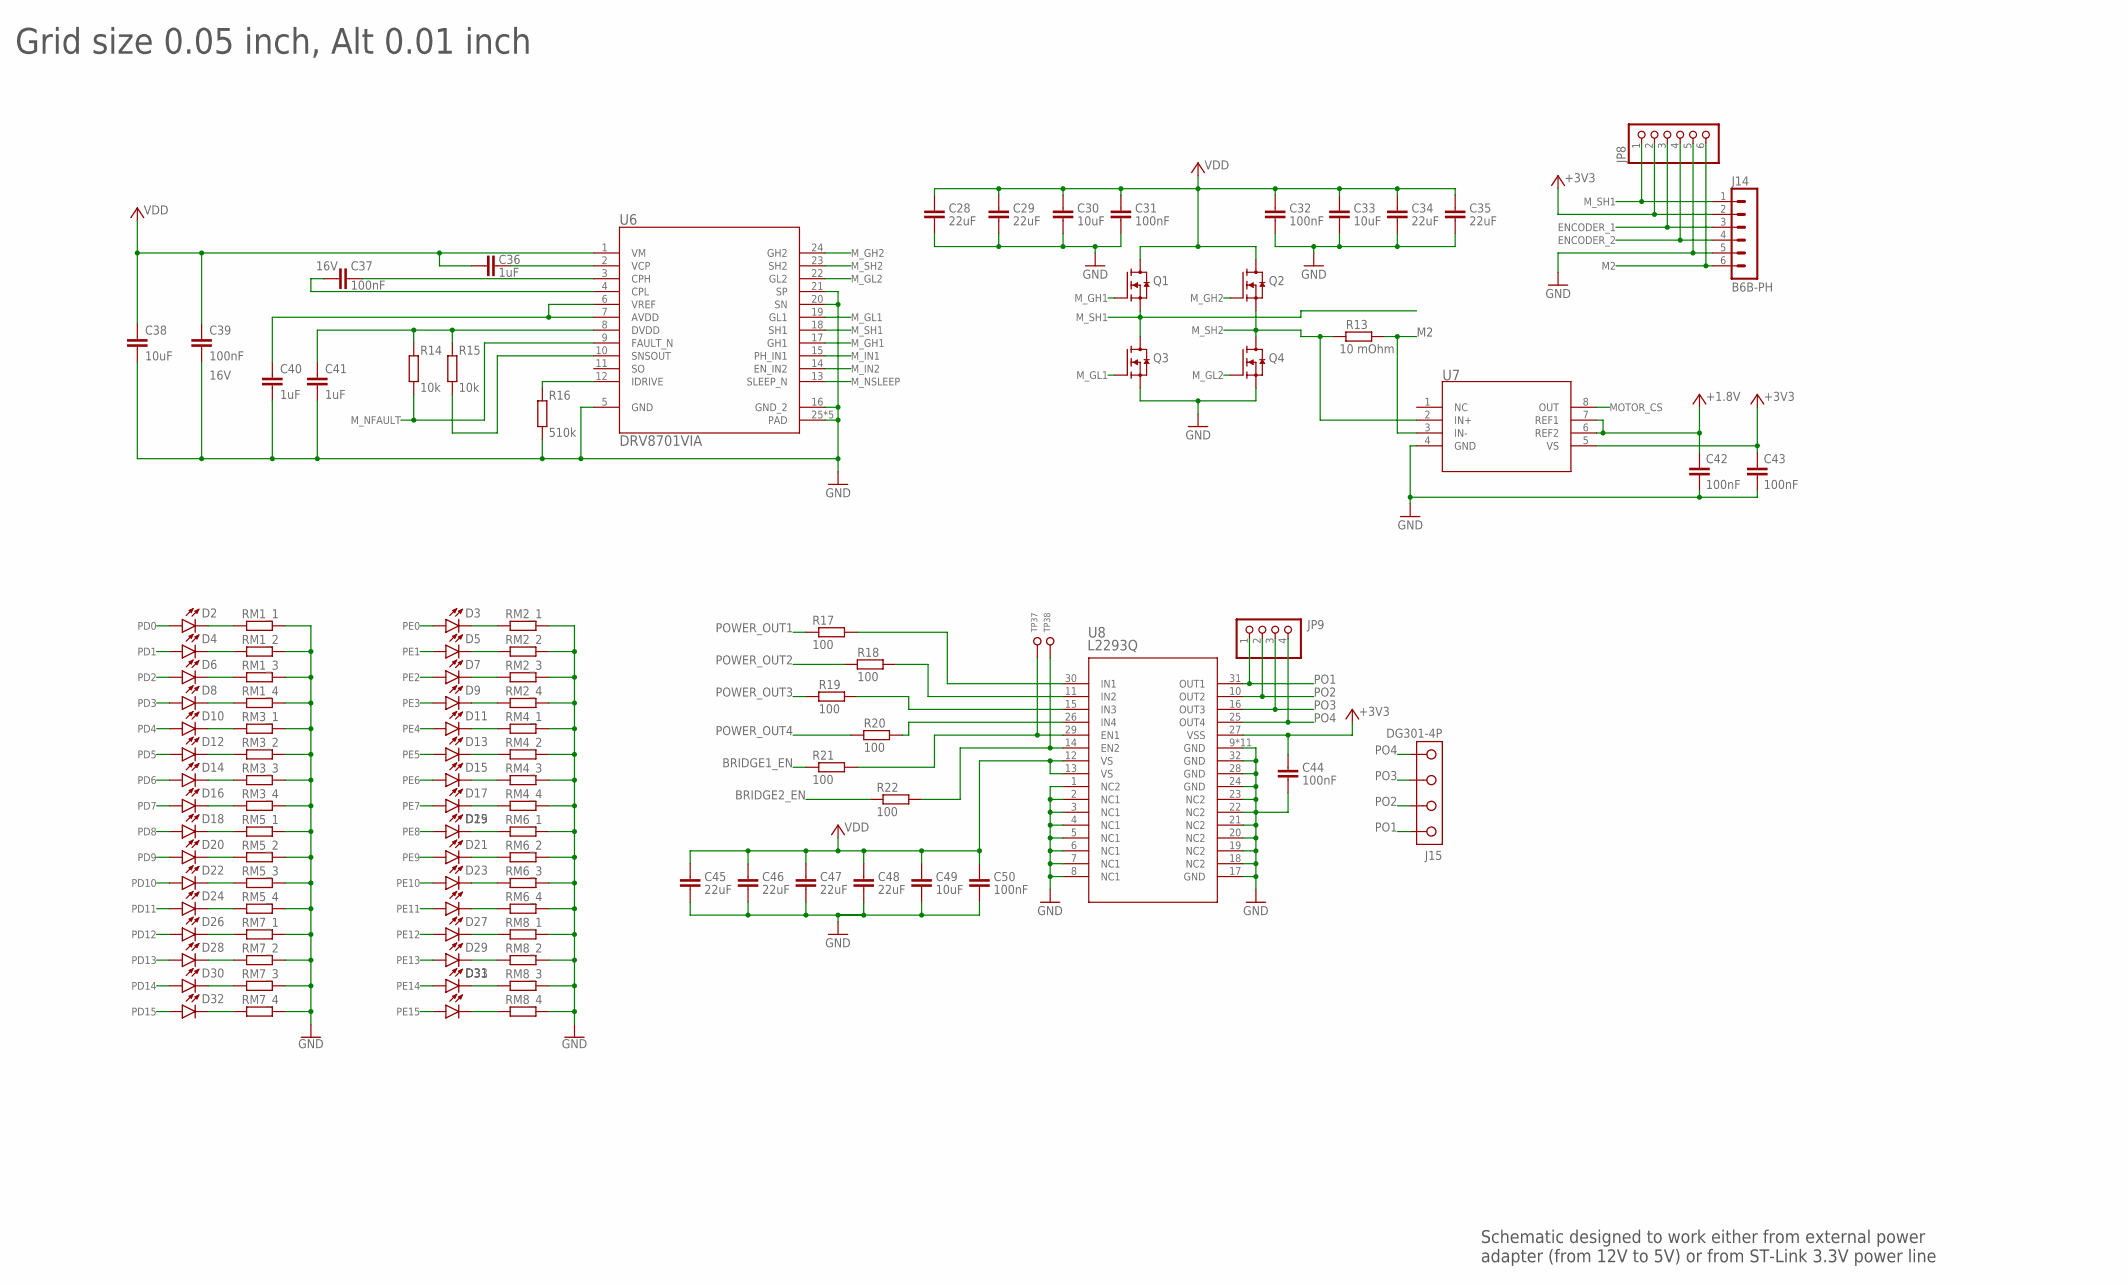
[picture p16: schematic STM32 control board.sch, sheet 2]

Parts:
C28, C29, C34, C35, C45, C46, C47, C48: 22uF; C1210; MANUFACTURER_PART_NUMBER GRM32ER61C476ME15L
C30, C33, C38, C49: 10uF; C1206; MANUFACTURER_PART_NUMBER CL31B106KAHNNNE
C31, C32, C37, C39, C42, C43, C44, C50: 100nF; C0402
C36, C40, C41: 1uF; C0603
D2, D3, D4, D5, D6, D7, D8, D9, D10, D11, D12, D13, D14, D15, D16, D17, D18, D19, D20, D21, D22, D23, D24, D25, D26, D27, D28, D29, D30, D31, D32, D33: Blue; LED-0805
J14: B6B-PH; B6B-PH-K
J15: DG301-4P
JP8: PINHD-1X6-OCT; 1X06
JP9: PINHD-1X4; 1X04
Q1, Q2, Q3, Q4: CSD15571Q2; SON2X2
R13: 10 mOhm; CS_R0805; MANUFACTURER_PART_NUMBER ERJ6CWDR010V
R14, R15: 10k; R0402
R16: 510k; R0402
R17, R18, R19, R20, R21, R22: 100; R0402
RM1, RM2, RM3, RM4, RM5, RM6, RM7, RM8: RES_ARRAY0603; 0603-ARC
TP37, TP38: TEST_PAD-[1.27MM_SK]; TP1.27MM_MASK_SILKSCREEN
U6: DRV8701VIA; VQFN-24-VIA
U7: INA240_TSSOP; TSSOP-8; MANUFACTURER_PART_NUMBER INA240
U8: L2293Q; QFN_293Q_STM

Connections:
+1.8V: C42.1, U7.6 (REF2), U7.7 (REF1); also elsewhere on the board
+3V3: C43.1, C44.1, J14.2, JP8.2, U7.5 (VS), U8.27 (VSS); also elsewhere on the board
AVDD1: C40.2, U6.6 (VREF), U6.7 (AVDD)
BRIDGE1_EN: R21.1; also elsewhere on the board
BRIDGE2_EN: R22.1; also elsewhere on the board
DRV2_SNSOUT: R15.1, U6.10 (SNSOUT)
DVDD2: C41.2, R14.2, R15.2, U6.8 (DVDD)
ENCODER_1: J14.3, JP8.3; also elsewhere on the board
ENCODER_2: J14.4, JP8.4; also elsewhere on the board
GND: C28.2, C29.2, C30.2, C31.2, C32.2, C33.2, C34.2, C35.2, C38.2, C39.2, C40.1, C41.1, C42.2, C43.2, C44.2, C45.2, C46.2, C47.2, C48.2, C49.2, C50.2, J14.5, JP8.5, Q3.S4 (S), Q3.S8 (S), Q4.S4 (S), Q4.S8 (S), R16.1, RM1.1, RM1.2 (1), RM1.3 (1), RM1.4 (1), RM2.1, RM2.2 (1), RM2.3 (1), RM2.4 (1), RM3.1, RM3.2 (1), RM3.3 (1), RM3.4 (1), RM4.1, RM4.2 (1), RM4.3 (1), RM4.4 (1), RM5.1, RM5.2 (1), RM5.3 (1), RM5.4 (1), RM6.1, RM6.2 (1), RM6.3 (1), RM6.4 (1), RM7.1, RM7.2 (1), RM7.3 (1), RM7.4 (1), RM8.1, RM8.2 (1), RM8.3 (1), RM8.4 (1), U6.5 (GND), U6.16 (GND_2), U6.20 (SN), U6.21 (SP), U6.25 (PAD), U6.26 (PAD), U6.27 (PAD), U6.28 (PAD), U6.29 (PAD), U7.4 (GND), U8.1 (NC2), U8.2 (NC1), U8.3 (NC1), U8.4 (NC1), U8.5 (NC1), U8.6 (NC1), U8.7 (NC1), U8.8 (NC1), U8.9 (GND), U8.17 (GND), U8.18 (NC2), U8.19 (NC2), U8.20 (NC2), U8.21 (NC2), U8.22 (NC2), U8.23 (NC2), U8.24 (GND), U8.28 (GND), U8.32 (GND), U8.P$1 (GND), U8.P$2 (GND), U8.P$3 (GND), U8.P$4 (GND), U8.P$5 (GND), U8.P$6 (GND), U8.P$7 (GND), U8.P$8 (GND), U8.P$9 (GND), U8.PAD (GND); also elsewhere on the board
M2: J14.6, JP8.6, R13.2, U7.3 (IN-)
MOTOR_CS: U7.8 (OUT); also elsewhere on the board
M_GH1: Q1.G3 (G), U6.17 (GH1)
M_GH2: Q2.G3 (G), U6.24 (GH2)
M_GL1: Q3.G3 (G), U6.19 (GL1)
M_GL2: Q4.G3 (G), U6.22 (GL2)
M_IN1: U6.15 (PH_IN1); also elsewhere on the board
M_IN2: U6.14 (EN_IN2); also elsewhere on the board
M_NFAULT: R14.1, U6.9 (FAULT_N); also elsewhere on the board
M_NSLEEP: U6.13 (SLEEP_N); also elsewhere on the board
M_SH1: J14.1, JP8.1, Q1.S4 (S), Q1.S8 (S), Q3.D1 (D), Q3.D2 (D), Q3.D5 (D), Q3.D6 (D), Q3.D7 (D), U6.18 (SH1)
M_SH2: Q2.S4 (S), Q2.S8 (S), Q4.D1 (D), Q4.D2 (D), Q4.D5 (D), Q4.D6 (D), Q4.D7 (D), R13.1, U6.23 (SH2), U7.2 (IN+)
unnamed: D16.- (C), RM3.5 (2)
unnamed: D14.- (C), RM3.6 (2)
unnamed: D12.- (C), RM3.7 (2)
unnamed: D10.- (C), RM3.8 (2)
unnamed: R17.2, U8.30 (IN1)
unnamed: D2.- (C), RM1.8 (2)
unnamed: D4.- (C), RM1.7 (2)
unnamed: D6.- (C), RM1.6 (2)
unnamed: D8.- (C), RM1.5 (2)
unnamed: R18.2, U8.11 (IN2)
unnamed: R19.2, U8.15 (IN3)
unnamed: R20.2, U8.26 (IN4)
unnamed: R21.2, TP37.1, U8.29 (EN1)
unnamed: R22.2, TP38.1, U8.14 (EN2)
unnamed: D18.- (C), RM5.8 (2)
unnamed: C37.1, U6.3 (CPH)
unnamed: D20.- (C), RM5.7 (2)
unnamed: D22.- (C), RM5.6 (2)
unnamed: D24.- (C), RM5.5 (2)
unnamed: D26.- (C), RM7.8 (2)
unnamed: D28.- (C), RM7.7 (2)
unnamed: D30.- (C), RM7.6 (2)
unnamed: D32.- (C), RM7.5 (2)
unnamed: C37.2, U6.4 (CPL)
unnamed: C36.2, U6.2 (VCP)
unnamed: D3.- (C), RM2.8 (2)
unnamed: D5.- (C), RM2.7 (2)
unnamed: D7.- (C), RM2.6 (2)
unnamed: R16.2, U6.12 (IDRIVE)
unnamed: D9.- (C), RM2.5 (2)
unnamed: D11.- (C), RM4.8 (2)
unnamed: D13.- (C), RM4.7 (2)
unnamed: D15.- (C), RM4.6 (2)
unnamed: D17.- (C), RM4.5 (2)
unnamed: D19.- (C), RM6.8 (2)
unnamed: D21.- (C), RM6.7 (2)
unnamed: D23.- (C), RM6.6 (2)
unnamed: D25.- (C), RM6.5 (2)
unnamed: D27.- (C), RM8.8 (2)
unnamed: D29.- (C), RM8.7 (2)
unnamed: D31.- (C), RM8.6 (2)
unnamed: D33.- (C), RM8.5 (2)
PD0: D2.+ (A); also elsewhere on the board
PD1: D4.+ (A); also elsewhere on the board
PD2: D6.+ (A); also elsewhere on the board
PD3: D8.+ (A); also elsewhere on the board
PD4: D10.+ (A); also elsewhere on the board
PD5: D12.+ (A); also elsewhere on the board
PD6: D14.+ (A); also elsewhere on the board
PD7: D16.+ (A); also elsewhere on the board
PD8: D18.+ (A); also elsewhere on the board
PD9: D20.+ (A); also elsewhere on the board
PD10: D22.+ (A); also elsewhere on the board
PD11: D24.+ (A); also elsewhere on the board
PD12: D26.+ (A); also elsewhere on the board
PD13: D28.+ (A); also elsewhere on the board
PD14: D30.+ (A); also elsewhere on the board
PD15: D32.+ (A); also elsewhere on the board
PE0: D3.+ (A); also elsewhere on the board
PE1: D5.+ (A); also elsewhere on the board
PE2: D7.+ (A); also elsewhere on the board
PE3: D9.+ (A); also elsewhere on the board
PE4: D11.+ (A); also elsewhere on the board
PE5: D13.+ (A); also elsewhere on the board
PE6: D15.+ (A); also elsewhere on the board
PE7: D17.+ (A); also elsewhere on the board
PE8: D19.+ (A); also elsewhere on the board
PE9: D21.+ (A); also elsewhere on the board
PE10: D23.+ (A); also elsewhere on the board
PE11: D25.+ (A); also elsewhere on the board
PE12: D27.+ (A); also elsewhere on the board
PE13: D29.+ (A); also elsewhere on the board
PE14: D31.+ (A); also elsewhere on the board
PE15: D33.+ (A); also elsewhere on the board
PO1: J15.1, JP9.1, U8.31 (OUT1)
PO2: J15.2, JP9.2, U8.10 (OUT2)
PO3: J15.3, JP9.3, U8.16 (OUT3)
PO4: J15.4, JP9.4, U8.25 (OUT4)
POWER_OUT1: R17.1; also elsewhere on the board
POWER_OUT2: R18.1; also elsewhere on the board
POWER_OUT3: R19.1; also elsewhere on the board
POWER_OUT4: R20.1; also elsewhere on the board
VDD: C28.1, C29.1, C30.1, C31.1, C32.1, C33.1, C34.1, C35.1, C36.1, C38.1, C39.1, C45.1, C46.1, C47.1, C48.1, C49.1, C50.1, Q1.D1 (D), Q1.D2 (D), Q1.D5 (D), Q1.D6 (D), Q1.D7 (D), Q2.D1 (D), Q2.D2 (D), Q2.D5 (D), Q2.D6 (D), Q2.D7 (D), U6.1 (VM), U8.12 (VS), U8.13 (VS); also elsewhere on the board

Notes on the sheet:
Grid size 0.05 inch, Alt 0.01 inch
16V
Schematic designed to work either from external power adapter (from 12V to 5V) or from ST-Link 3.3V power line

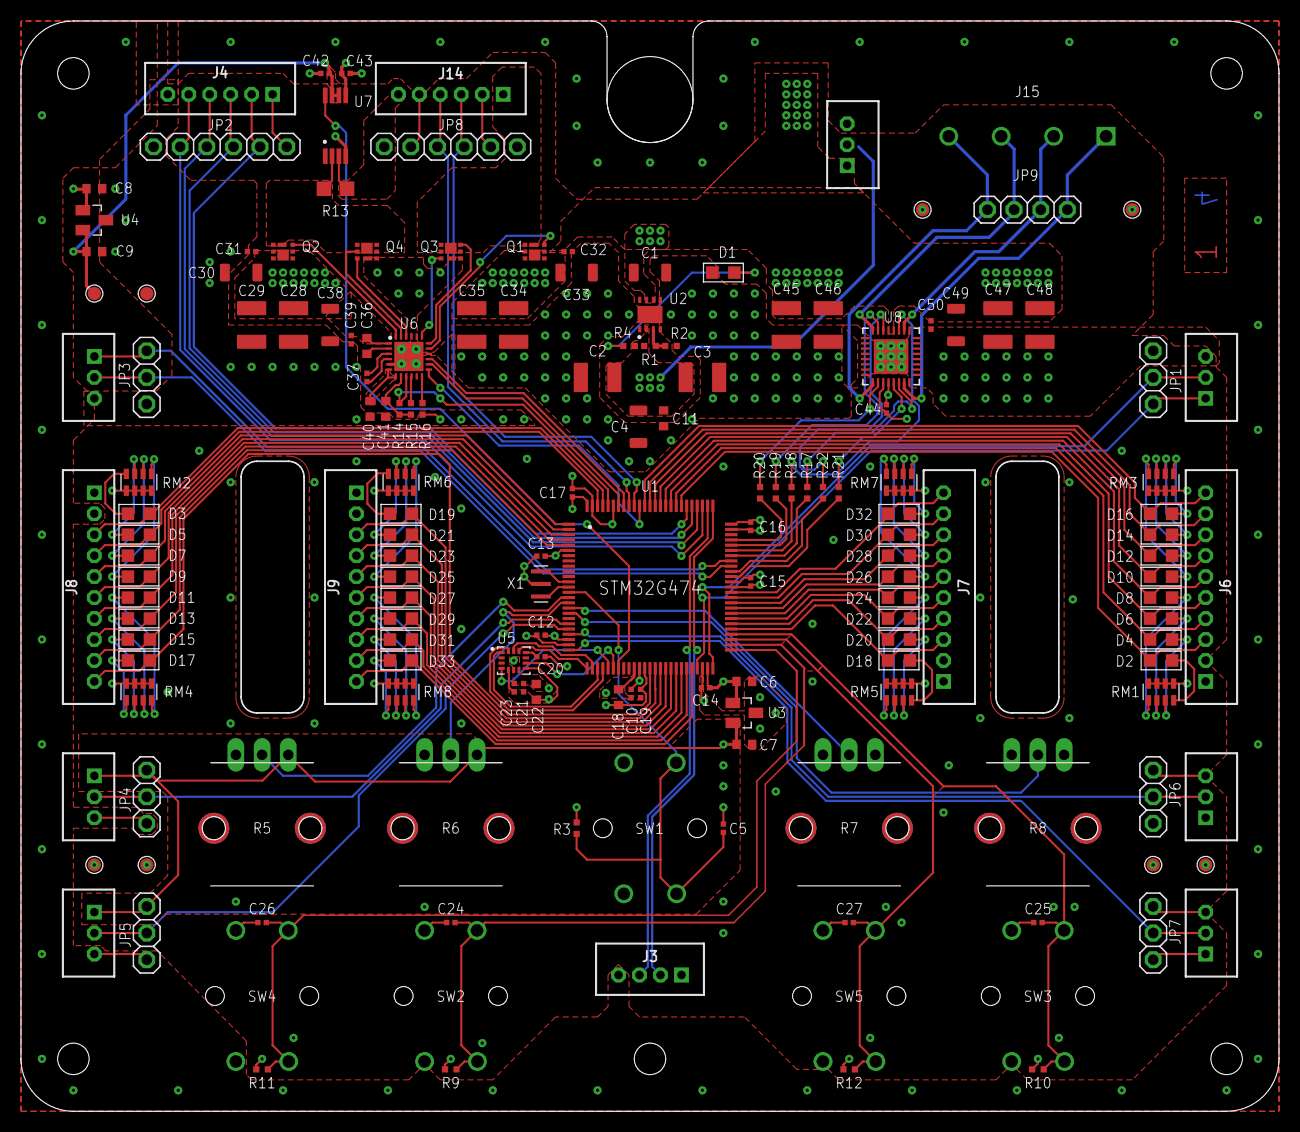
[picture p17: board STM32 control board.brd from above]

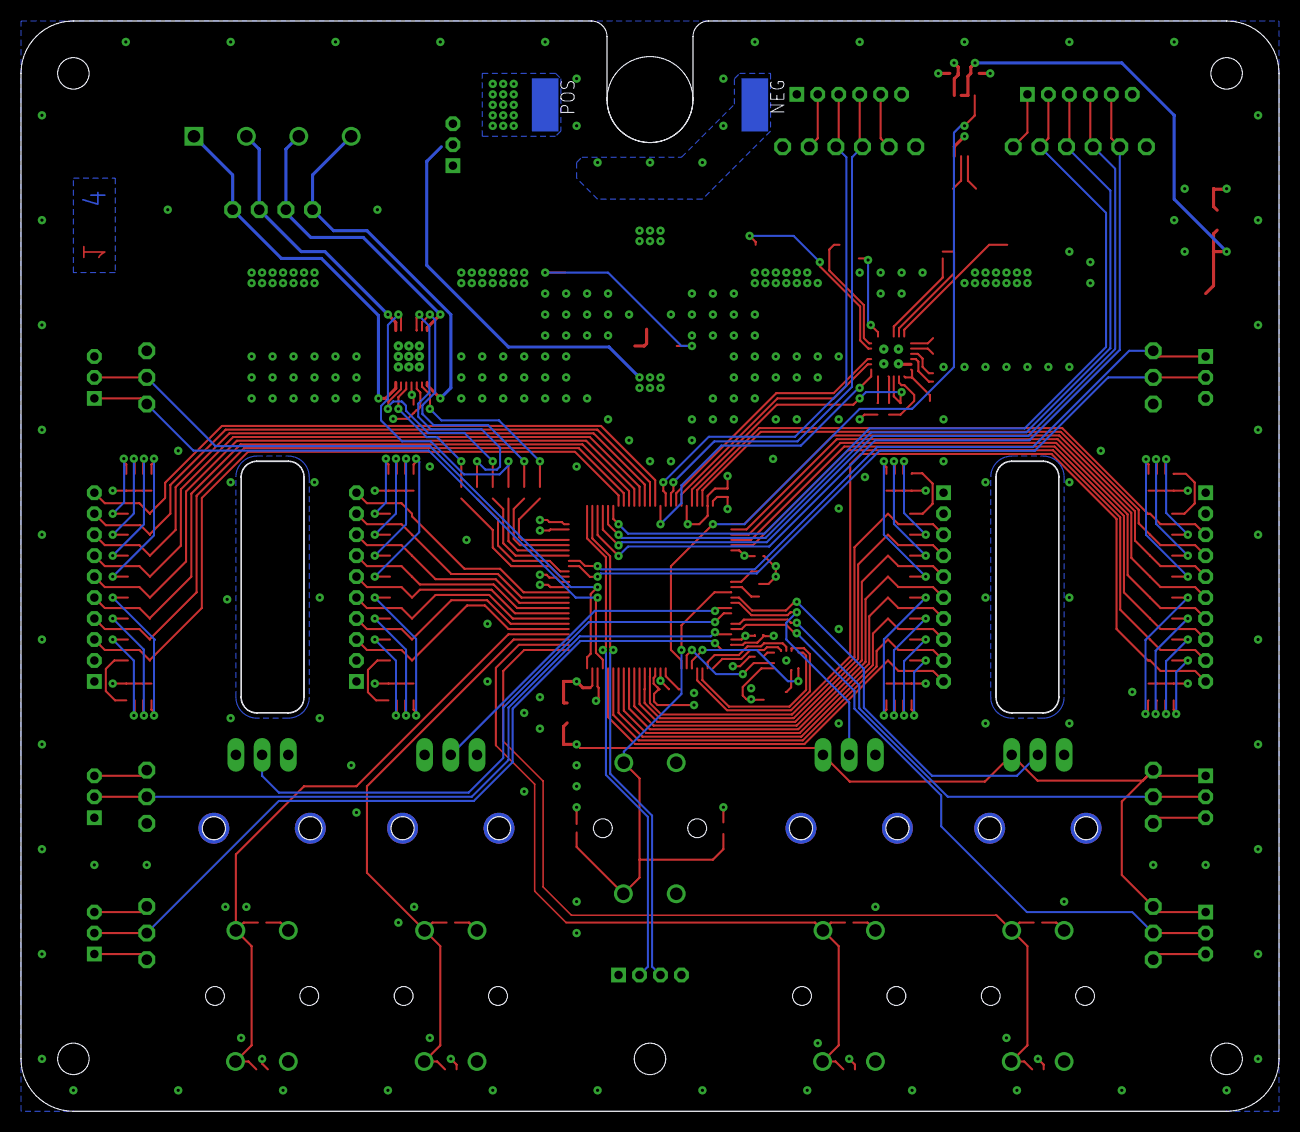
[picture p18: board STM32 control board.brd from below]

Board: 4 copper layers, 120.0 x 104.0 mm, 165 parts (2 on the bottom side), 140 nets.

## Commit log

2020-07-04 Basic shematic creation
    [STM32 control board.sch]
2020-07-09 Update STM32 control board.sch
    Review
    [STM32 control board.sch]
2020-07-09 changed power diode position
    [STM32 control board.sch]
2020-07-12 Update STM32 control board.sch
    [STM32 control board.sch]
2020-07-12 board created
    [STM32 control board.brd, STM32 control board.sch]
2020-07-13 Placed connectors as i see
    [STM32 control board.brd]
2020-07-13 Files reorganization
    [STM32 control board.brd, STM32 control board.sch]
2020-07-13 renumbered schematic
    [STM32 control board.brd, STM32 control board.sch]
2020-07-16 Can removed
    [STM32 control board.brd, STM32 control board.sch]
2020-07-19 for BOM review
    [STM32 control board.brd, STM32 control board.sch]
2020-07-26 components placement for review
    [STM32 control board.brd, STM32 control board.sch]
2020-07-26 cutout fixes
    [STM32 control board.brd]
2020-07-26 Not finished consept
    [STM32 control board.brd, STM32 control board.sch]
2020-07-27 consept update
    [STM32 control board.brd, STM32 control board.sch]
2020-07-28 placement fixes.
    Current size is 104*120mm
    [STM32 control board.brd, STM32 control board.sch]
2020-07-29 screw terminal placement fix
    [STM32 control board.brd, STM32 control board.sch]
2020-07-29 routing part 2
    [STM32 control board.brd, STM32 control board.sch]
2020-07-29 routing part 3
    [STM32 control board.brd, STM32 control board.sch]
2020-07-30 polygons part 1
    [STM32 control board.brd]
2020-08-01 for routing rewiew
    [STM32 control board.brd, STM32 control board.sch]
2020-08-11 added stiching vias
    [STM32 control board.brd]
2020-08-11 small gnd plane fix
    [STM32 control board.brd]
2020-08-13 fixed position of power jack
    [STM32 control board.brd]
2020-08-14 3d model updated
    [STM32 control board.brd]
2020-08-14 Added some changes to routing
    [STM32 control board.brd]
2020-08-19 silkscreen first time uploaded
    [STM32 control board.sch]
2020-08-20 Silkscreen for rewiew
    [STM32 control board.sch]
2020-08-21 Documentation for rewiew
    [pick-and-place-smd.xlsx, pick-and-place-tht.xlsx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]
2020-08-22 Addded drill file
    [drill_1_16.xln]
2020-08-22 added zip file with gerbers
2020-08-24 silckscreen fixes after rewiew
    [silkscreen_top.gbr]
2020-09-11 board file
2020-10-08 Create STM32 control board - ESCD.sch
    [STM32 control board - ESCD.sch]
2021-01-14 Updated the README and added schematics
2021-01-14 Added the forgotten schematic

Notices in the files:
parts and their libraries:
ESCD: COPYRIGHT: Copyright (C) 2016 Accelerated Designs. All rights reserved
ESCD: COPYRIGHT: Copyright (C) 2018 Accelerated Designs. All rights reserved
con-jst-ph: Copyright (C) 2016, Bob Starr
